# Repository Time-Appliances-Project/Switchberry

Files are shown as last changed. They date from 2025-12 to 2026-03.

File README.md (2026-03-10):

# Switchberry

## Raspberry Pi Compute Module based, Managed 1G Ethernet Switch with PTP Support
Switchberry is a Raspberry Pi CM4–controlled Ethernet switching + timing platform built around a **Microchip KSZ9567** and a **Renesas 8A34004 ClockMatrix DPLL**. It’s designed for **PTP / SyncE / timing lab** workflows while staying flexible enough to run as a compact managed switch/router with precise timing I/O.

529070621-42df475b-2fe9-462f-92c0-70f97fde4533

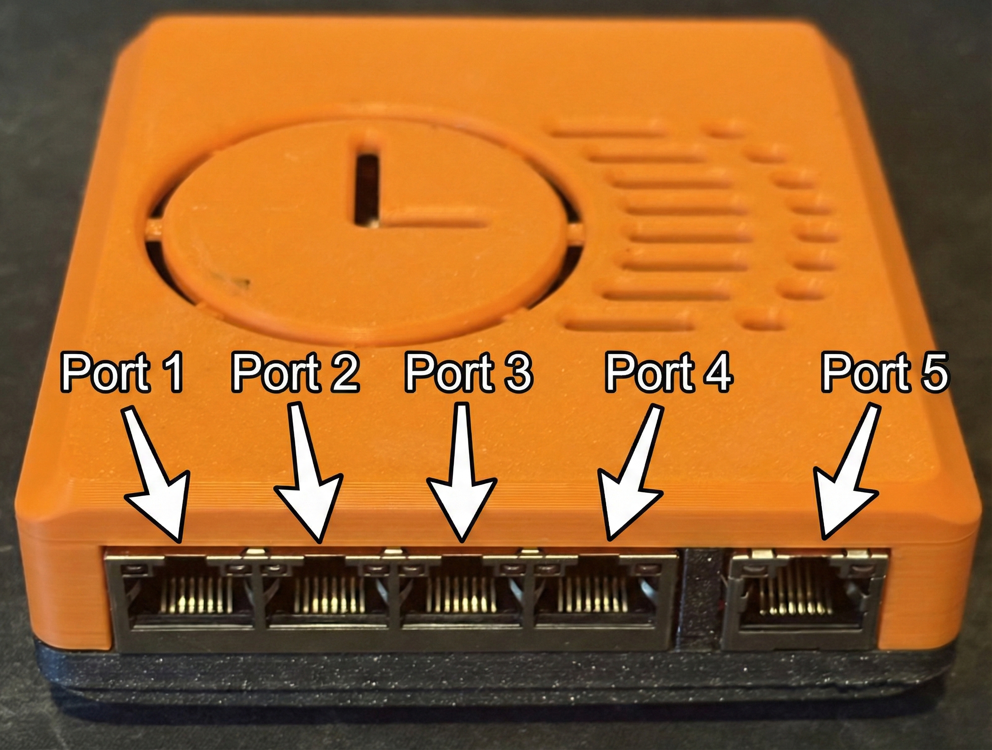
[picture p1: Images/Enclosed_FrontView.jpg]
Switchberry board Front view

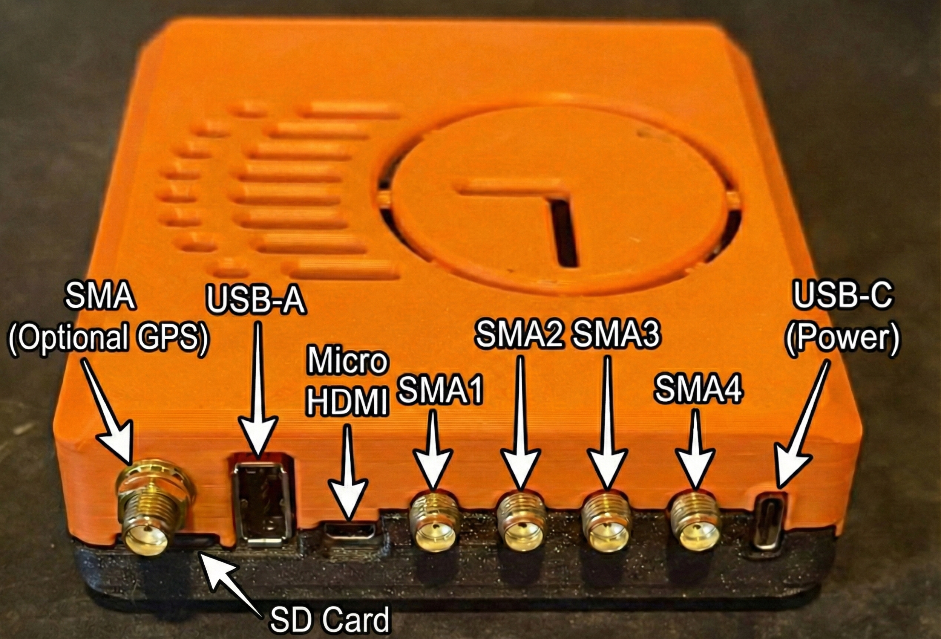
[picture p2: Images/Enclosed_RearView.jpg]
Switchberry board Rear view


---

## Order

**Switchberry is available for purchase on Tindie:**

👉 **[Buy Switchberry on Shopify](https://pmqipr-s3.myshopify.com/collections/switchberry-bundles)**

👉 **[Buy Switchberry on Tindie](https://www.tindie.com/products/timeappliances/switchberry/)**

---

## Table of Contents

- [Order](#order)

- [Quick Start](#quick-start)
  - [Out-of-the-Box Behavior](#out-of-the-box-behavior)
  - [Accessing the Raspberry Pi CM4](#accessing-the-raspberry-pi-cm4)
  - [Customize & Monitor](#customize--monitor)
- [Key Features](#key-features)
- [Hardware Overview](#hardware-overview)
- [Timing & Sync Capabilities](#timing--sync-capabilities)
- [Typical Use Cases](#typical-use-cases)
- [Notes](#notes)
- [License](#license)

**Software & Tools**

| Guide | Description |
| :--- | :--- |
| [Software Quick Start](Software/README.md) | Timing/PTP setup, config wizard, detailed from-scratch install |
| [Switch CLI](Software/switch/README.md) | KSZ9567 port status, counters, and init via SPI |
| [Daemons & Services](Software/daemons/README.md) | Systemd service chain, boot sequence, Makefile control |
| [ClockMatrix Utilities](Software/clockmatrix/README.md) | dplltool, config.py wizard, apply_timing.py, DPLL monitor |
| [Enclosure](Enclosure/README.md) | Enclosure design files |
| [Partial Schematic](PartialSchematic/README.md) | Board schematic reference |

---

## Quick Start

### Out-of-the-Box Behavior

With no configuration, Switchberry works as a **plug-and-play Layer 2 unmanaged Ethernet switch** with **PTP hardware transparent clock** enabled:

- **All 5 front-panel RJ45 ports** are on the same switch plane and forward traffic at line rate — just plug in Ethernet cables
- The CM4 is connected to the switch via an **internal port that is always up**, so **any front-panel port** can be used to reach the CM4 over the network
- **PTP transparent clock** is active by default — PTP packets are forwarded with hardware residence-time correction, no setup needed
- No VLANs, IP configuration, or switch management required to start using it as a switch

### Accessing the Raspberry Pi CM4

**Default login:** `pi` / `password`

The CM4 is available through three interfaces:

| Method | Connector | Details |
| :--- | :--- | :--- |
| **Ethernet (DHCP)** | Any front-panel RJ45 port | CM4 obtains an IP via DHCP. SSH in with `ssh pi@<ip-address>` — use `find_switchberry.py` or check your router to find the IP. |
| **Serial console** | Micro-USB (side panel) | Appears as a USB UART. Connect with **PuTTY** or **Tera Term** (Windows) or **tio** (Linux) at **115200 baud**. On a fresh SD card image, add `enable_uart=1` to `config.txt` first. |
| **Display + keyboard** | Micro-HDMI + USB-A | Connect a monitor via micro-HDMI and a keyboard via USB-A for direct console/desktop access. |

> **Tip:** Use `find_switchberry.py` from your PC to automatically discover Switchberry devices on your LAN:
> ```bash
> python3 find_switchberry.py
> ```

### Customize & Monitor

Clone the repo and make scripts executable:

```bash
cd ~/
git clone https://github.com/Time-Appliances-Project/Switchberry
cd Switchberry/Software
git config core.fileMode false
chmod +x sb-*.sh install_all.sh
```

Then configure and apply:

```bash
./sb-config.sh          # Interactive wizard — configure PTP role, timing sources, SMA routing
sudo ./sb-reinstall.sh  # Reinstall & restart (runs in background — safe over SSH)
./sb-status.sh          # Check DPLL lock state, PTP sync, and service health from the CLI
```

A **web status dashboard** also runs on port **8080** — open `http://<switchberry-ip>:8080` in any browser on the same network to see live system status.

For the full guide, see the **[Software Quick Start Guide](Software/README.md)**.

---

## Key Features

- **5× front-panel RJ45** ports driven by a **KSZ9567** switch
- **Raspberry Pi CM4** controller managing the switch over **SPI**
- **Renesas 8A34004 ClockMatrix DPLL** as the central timing hub
- **Local TCXO** reference for the ClockMatrix (drives derived clocks)
- **OCP M.2 GNSS** slot (GPS/GNSS timing card support)
- **PCIe M.2 2230** slot (Wi-Fi 6E / Wi-Fi 7 modules)
- **4× rear SMA** ports with muxing for multiple input/output routing options
- **SyncE recovery** from the switch into the DPLL (endpoint / boundary clock roles)
- **PTP modes**: hardware transparent clock (typical) or Linux DSA for software-defined behavior
- CM4 ↔ DPLL **PPS routing** supports both **PTP Grandmaster** and **PTP client** workflows

---

## Hardware Overview

### Ethernet Switching (KSZ9567)
- **Switch:** Microchip **KSZ9567**
- **Front panel:** **5× RJ45** ports
- **SFP:** Present on KSZ9567 but **unused** in this design (not used because it doesn’t support PTP)

### Controller / Host (CM4)
- **Compute:** Raspberry Pi **CM4**
- **Switch management:** CM4 controls the KSZ9567 over **SPI**
- **Uplink path to the switch:**
  - CM4 Ethernet MAC → **KSZ9031 PHY** → KSZ9567 (connected as one switch port)

### Timing Core (ClockMatrix)
- **DPLL:** **Renesas 8A34004 ClockMatrix**
  - Central point for all timing signals (distribution, recovery, synthesis)
- **Reference oscillator:** **Local TCXO**
  - Feeds the ClockMatrix and serves as the base reference for derived clocks

### Expansion
- **GNSS:** **OCP M.2 GNSS** slot for GPS/GNSS cards
- **Wi-Fi:** **PCIe M.2 2230** slot for Wi-Fi modules (Wi-Fi 6E / Wi-Fi 7 capable cards)

### Rear I/O (SMA)
- **4× SMA ports** on the back panel
- Each SMA has **muxing**, allowing configurable **input/output** options depending on timing mode and setup

---

## Timing & Sync Capabilities

### SyncE
- Switchberry can **recover the SyncE clock** from the **KSZ9567** and feed it into the **ClockMatrix DPLL**.
- Enables operation as a **SyncE endpoint** or **SyncE boundary clock** (and equivalent roles depending on configuration).

### PTP (IEEE 1588)
The KSZ9567 can be operated in multiple modes depending on the use case:

- **Transparent Clock (typical):**
  - KSZ9567 runs in **transparent clock mode** with **hardware forwarding**.
- **Linux DSA (optional):**
  - Run the switch under the **DSA kernel architecture** to behave more like a **software router**
  - Useful for experimentation with **boundary clock / software-defined forwarding** behavior

### PPS Routing (CM4 ↔ DPLL)
- The **PPS associated with the CM4 Ethernet port** routes to the **DPLL** as **both input and output**.
- Supports:
  - **PTP Grandmaster operation**
    - CM4 disciplines to a **PPS input from the DPLL**, derived from **GNSS** or an **external 1PPS** source.
  - **PTP client operation**
    - CM4 recovers timing via **PTP over the Ethernet switch** and provides **1PPS to the DPLL**.

---

## Typical Use Cases

- **PTP networking**
  - Transparent clock, boundary clock experimentation, lab deployments
- **SyncE networking**
  - Endpoint / boundary clock setups using recovered SyncE into the DPLL
- **PTP Grandmaster**
  - GNSS-referenced or externally referenced timing with PPS discipline
- **PTP client**
  - Recover PPS via PTP and feed the DPLL
- **TSN experimentation**
  - With additional scripting/development
- **DPLL development**
  - Clocking experiments, holdover testing, input qualification, output synthesis
- **Arbitrary frequency generator**
  - Using ClockMatrix outputs via configurable SMA routing
- **PPS ↔ frequency conversion**
  - Convert/derive timing signals via the DPLL and output routing
- **Wi-Fi bridge**
  - Wi-Fi 6E / Wi-Fi 7 connectivity via M.2 2230 (e.g., bridging/edge deployments)

---

## Notes

- The KSZ9567 **SFP port is unused** in this design because it doesn’t support PTP for the intended timing workflows.
- SMA functions are **mode-dependent** and determined by the mux configuration and ClockMatrix setup.

---

## License

This project is licensed under the Creative Commons Attribution-NonCommercial 4.0 International License (CC BY-NC 4.0).

You are free to:

Share — copy and redistribute the material in any medium or format
Adapt — remix, transform, and build upon the material
Under the following terms:

Attribution — You must give appropriate credit, provide a link to the license, and indicate if changes were made.
NonCommercial — You may not use the material for commercial purposes.
For full details, see: https://creativecommons.org/licenses/by-nc/4.0/

As the project creator, I reserve the right to use this material commercially or under any other terms.

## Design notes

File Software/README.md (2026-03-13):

# Switchberry Timing Quick Start

This guide gets you from “fresh install” to a working timing/PTP setup, and shows how to customize behavior using the `config.py` wizard and the daemon Makefile.

**↑ [Back to main README](../README.md)**

## Table of Contents

- [System Overview](#system-overview)
- [Default behavior (out of the box)](#default-behavior-out-of-the-box)
- [Quick start: customize your timing/PTP setup](#quick-start-customize-your-timingptp-setup)
- [Detailed setup](#detailed-setup)

**Related Guides:** [Switch CLI](switch/README.md) · [Daemons & Services](daemons/README.md) · [ClockMatrix Utilities](clockmatrix/README.md)

### System Overview

```mermaid
graph TD
    subgraph Sources [Timing Sources]
        GPS[GPS Receiver]
        SyncE[SyncE Network]
        SMA_In[SMA Inputs]
    end

    subgraph Switchberry
        direction TB
        DPLL[8A34004 DPLL]
        CM4[Compute Module 4]
        Switch[KSZ9567 Switch]
    end

    subgraph Outputs [Timing Distribution]
        PTP[PTP Network]
        SMA_Out[SMA Outputs]
    end

    %% Flow
    GPS -->|1PPS| DPLL
    SMA_In -->|Freq/Time| DPLL
    SyncE -->|Recovered Clock| Switch
    Switch -->|25MHz Ref| DPLL

    DPLL -->|1PPS| CM4
    DPLL -->|Freq & 1PPS| SMA_Out
    
    CM4 -->|System Time| PTP
    Switch -->|PTP Packets| PTP
```

---

## Default behavior (out of the box)

If you haven’t customized `/etc/startup-dpll.json`, the default setup is:

### PTP
- **Role:** **Grandmaster (GM)**
- **Mode:** **Unicast** (reduces message flooding; safer on shared networks)

### Input priorities
- **Time sources**
  1. **GPS** (highest priority for time)
  2. **SMA4** = 1PPS input (fallback time behind GPS)

- **Frequency sources**
  1. **SMA1** = 10MHz input (highest priority for frequency)

### Outputs
- **SMA3** = 1PPS output (or other frequency)
- **SMA2** = 10MHz output (**frequency-only**, V6 board - not phase-aligned)

> **V6 Board Note:** **SMA2** is routed via Channel 5 (SyncE frequency channel) and only
> provides frequency alignment, not phase alignment. For phase-aligned 1PPS output,
> use **SMA4** instead (which is routed via Channel 6).

### Advanced: Hardware SMA Mapping
For users debugging schematics or low-level GPIO code, here is the mapping between Rear-Panel labels (User) and Schematic labels (Hardware):

| User Label (Rear) | Hardware Label (Schematic) |
| :--- | :--- |
| **SMA1** | SMA4 |
| **SMA2** | SMA3 |
| **SMA3** | SMA2 |
| **SMA4** | SMA1 |

### NTP Server (GM+GPS only)

When configured as a **PTP Grandmaster with GPS**, Switchberry automatically serves **NTP** (Stratum 1) to the local network. The full time chain is:

```
GPS → DPLL → ts2phc → PHC (TAI) → phc2sys (-O -37) → System Clock (UTC) → chrony → NTP
```

- **Guard script** (`switchberry_chrony_guard.sh`): Only starts `chronyd` once `ts2phc` has converged. If GPS is lost or the DPLL goes unstable, chrony is stopped so stale time is never served. It restarts automatically when GPS recovers.
- **Config:** `/etc/switchberry/chrony-switchberry.conf`
- NTP is **not served** in CLIENT or NONE modes.

> **Dependency:** `chrony` must be installed: `sudo apt install chrony`.
> The stock `chronyd.service` is automatically disabled by `sb-reinstall.sh` to prevent port 123 conflicts.

#### Testing NTP from another device

From any device on the same network as the Switchberry:

**Linux:**
```bash
ntpdate -q <switchberry-ip>
# Install if missing: sudo apt install ntpdate
```

**macOS:**
```bash
sntp <switchberry-ip>
```

**Windows (PowerShell):**
```powershell
w32tm /stripchart /computer:<switchberry-ip> /samples:3
```

You should see **Stratum 1** and an offset near zero (a few ms is normal over Ethernet).

### System Clock Sync (GM+GPS and CLIENT)

The system clock (`CLOCK_REALTIME`) is automatically synced from the PHC via `phc2sys` in both **GM+GPS** and **CLIENT** modes:

- **GM+GPS:** `phc2sys` starts when `ts2phc` converges (PHC has GPS time).
- **CLIENT:** `phc2sys` starts when `ptp4l` is locked (servo `s2`, tight offsets).
- **Guard script** (`switchberry_phc2sys_guard.sh`): Stops `phc2sys` when the upstream time source is lost, restarts when recovered.
- **TAI→UTC:** `phc2sys` runs with `-O -37` to convert from the PHC's TAI time to the system clock's UTC.

---

## Quick start: customize your timing/PTP setup

### 1) Clone the github software
```bash
cd ~/
git clone https://github.com/Time-Appliances-Project/Switchberry
cd Switchberry/Software 
git config core.fileMode false
chmod +x sb-*.sh install_all.sh
```

### 2) Run the config wizard
This script runs the wizard and automatically installs the generated configuration to `/etc/startup-dpll.json`.

```bash
./sb-config.sh
```

### 3) Apply changes and restart services
This script recompiles tools, installs services, and restarts the PTP stack.

```bash
sudo ./sb-reinstall.sh
```

### 4) Check Status
Monitor DPLL lock state, PTP synchronization, and service health.

```bash
./sb-status.sh
```

### 5) Web Status Dashboard
A built-in web server runs on port **8080** (HTTP) and **8443** (HTTPS), showing a live dashboard with system identity, configuration, service status, DPLL state, and PTP sync info. It auto-refreshes every 10 seconds.

From any browser on the same network, open:
```
http://<switchberry-ip>:8080
```

> **Tip:** Use the `find_switchberry.py` script (in the repo root) from your PC to automatically discover Switchberry devices on your LAN:
> ```bash
> python3 find_switchberry.py
> ```

### 6) (Optional) Customize PTP configuration
If you need to change PTP profiles (e.g. Unicast vs Multicast), edit the config files managed by the services:
- Client: `~/Switchberry/Software/daemons/ptp4l-switchberry-client.conf`
- Grandmaster: `~/Switchberry/Software/daemons/ptp4l-switchberry-gm.conf`
Then run `sudo ./sb-reinstall.sh` to apply.

## Detailed setup 

This section is only if you want to start from a fresh SD card for instance. 

To access the Switchberry, you can use 

1. Micro-HDMI for monitor, USB-A for keyboard
2. Micro-USB on side. This will come up as UART to the CM4.
	To access this with a fresh SD card, you'll need to edit config.txt into the SD card to enable the UART.

In config.txt, add these at the end under [all]:

```bash
dtparam=spi=on
enable_uart=1
uart_2ndstage=1
dtoverlay=disable-bt
dtoverlay=switchberrytc
#dtoverlay=ksz9567
dtoverlay=spi0-1cs
dtoverlay=uart5,txd5_pin=12,rxd5_pin=13
dtoverlay=pcie-32bit-dma
dtparam=i2c_vc=off
hdmi_force_hotplug=1
```

### 1) Setup SD-card
Edit config.txt in bootfs of SD card like above. Enables UART and boot without monitor.

### 2) Clone the github software
```bash
cd ~/
git clone https://github.com/Time-Appliances-Project/Switchberry
cd Switchberry 
```

### 3) Install a bunch of dependencies

```bash
sudo apt update
sudo apt install bc bison flex libssl-dev make screen vim automake iperf tshark autoconf libmnl-dev libmnl-doc jq gpsd gpsd-clients socat linuxptp 
```

### 4) Clone kernel sources
Instructions for building CM4 kernel are here: https://www.raspberrypi.com/documentation/computers/linux_kernel.html

```bash 
cd ~/
mkdir kernel
cd kernel
git clone --depth=1 https://github.com/raspberrypi/linux
cd linux
# updated .config with additional items needed by switchberry like MDIO and others 
cp ~/Switchberry/Software/kernel/.config ./.config
# device tree overlays for switchberry, for both default ("Transparent clock") and DSA ("Boundary clock"), and Makefile
cp ~/Switchberry/Software/kernel/ksz9567-overlay.dts arch/arm/boot/dts/overlays/
cp ~/Switchberry/Software/kernel/switchberrytc-overlay.dts arch/arm/boot/dts/overlays/
cp ~/Switchberry/Software/kernel/copy_Makefile arch/arm/boot/dts/overlays/Makefile
```

### 5) Rebuild kernel with updated config and overlays

This step will take significant time!
```bash 
cd ~/kernel/linux
KERNEL=kernel8

# THIS STEP ESPECIALLY takes a long time , I run it in screen so if you disconnect it keeps going
#screen -S test # do this if you're familiar with screen so ssh connection can drop 
# if it asks questions, just hold enter for defaults
make -j6 Image.gz modules dtbs ; sudo make -j6 modules_install

KERNEL=kernel8
sudo cp /boot/firmware/$KERNEL.img /boot/firmware/$KERNEL-backup.img
sudo cp arch/arm64/boot/Image.gz /boot/firmware/$KERNEL.img
sudo cp arch/arm64/boot/dts/broadcom/*.dtb /boot/firmware/
sudo cp arch/arm64/boot/dts/overlays/*.dtb* /boot/firmware/overlays/
sudo cp arch/arm64/boot/dts/overlays/README /boot/firmware/overlays/
```

### 6) Reboot

```bash
sudo reboot
```

### 7) Install third party dependencies

#### spidev-test

```bash
cd ~/kernel/linux/tools/spi
make clean; make all; sudo make install
```

#### mdio-tools

```bash
cd ~/
git clone https://github.com/wkz/mdio-tools
cd mdio-tools/kernel
KDIR=~/kernel/linux/
make all; sudo make install 
cd .. 
./autogen.sh
./configure --prefix=/usr && make all && sudo make install
```

#### testptp

```bash
cd ~/kernel/linux/tools/testing/selftests/ptp
gcc -Wall -lrt testptp.c -o testptp
sudo cp testptp /usr/bin/
```

### 8) Build & Install everything for Switchberry

```bash
cd ~/Switchberry/Software/
chmod +x install_all.sh
sudo ./install_all.sh
```

### 9) Customize 

Follow quick-start guide above at this point, everything should be installed!

You need to create a /etc/startup-dpll.json for everything to get configured and operate properly.

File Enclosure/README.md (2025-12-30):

# Switchberry 3D Printed Case Instructions



The Switchberry 3D case is designed to be printed in two parts: a top cover and bottom plate. The bottom has two holes for heatsinks / airflow, and the top is ventilated in case you'd like to add on a fan, attached to the small JST SH (1mm) fan header on the Switchberry.

The 3D printable STL files are available in this directory:

  - [Switchberry_Case_v5_Top.stl](Switchberry_Case_v5_Top.stl)
  - [Switchberry_Case_v5_Bottom.stl](Switchberry_Case_v5_Top.stl)

It is recommended you print the top out of a material which can take some heat without deforming. The Switchberry shouldn't get *too* hot, but using PETG or ASA is a better option than PLA.

## Needed parts

The links below go to Amazon, but you can buy these parts from wherever you'd like:

  - [4x M3x10 (+6mm) Male to Female Brass Threaded Spacers](https://www.amazon.com/dp/B07BLSRZYJ) (to provide adequate space between the top cover and the PCB)
  - [4x M3x12 SHCS Screws](https://www.amazon.com/dp/B0FGV5FCBN) (to attach the bottom to the top)
  - [4x round rubber feet](https://www.amazon.com/dp/B08GLJB3Z4) (to hold Switchberry stably on a desk or shelf, and provide convective airflow under the board)



  1. Print the top and bottom case on a 3D printer (no supports required). I printed mine in ASA/PLA, but any material should be okay, depending on your environmental conditions and printer capabilities.
  3. Screw the M3x10 threaded spacers into the standoffs in the top case; this will require some force, so it is recommended you use a nut driver instead of trying to thread them in by hand.
  3. (Optionally, if using M.2 GPS module) Install GPS module into Switchberry, and plug in GPS U.FL to SMA female cable. Insert female SMA end into the hole in the top case and secure with included nut.
  4. Place the Switchberry board into the top case, Ethernet port side first, and ensure everything is aligned properly.
  5. Place the bottom cover over the Switchberry board, being careful to start with the post between the Ethernet ports (it will need to seat into the recess in the top cover), then make the rest of the case flush with the top cover.
  6. Screw four M3x12 SHCS screws into the four screw holes in the bottom cover. These can be a tight fit, depending on the accuracy of your 3D print.
  7. Place four adhesive rubber feet over the four circular foot pads on the bottom cover.

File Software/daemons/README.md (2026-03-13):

# Switchberry Daemons & Makefile Control

This directory contains the **systemd services** that bring up Switchberry’s timing + switch + PTP stack, plus a **Makefile** that installs and controls the whole set.

---

## Boot / runtime service chain

The system is intended to start in this order:

```mermaid
sequenceDiagram
    participant Boot as System Boot
    participant Apply as apply-timing.service
    participant Init as full-init.service
    participant Monitor as dpll-monitor.service
    participant Role as ptp-role.service
    participant PTP as PTP Daemons

    Note over Boot,PTP: Systemd Dependency Chain

    Boot->>Apply: 1. Program 8A34004 (DPLL)
    Apply->>Init: 2. Initialize Switch (KSZ9567)
    Init->>Monitor: 3. Start DPLL Monitor
    Init->>Role: 4. Determine PTP Role
    Role->>PTP: 5. Launch ptp4l / ts2phc
```

1. **Init DPLL + board multiplexers**
   - **Service:** `switchberry-apply-timing.service`
   - **Runs:** `/usr/local/sbin/apply_timing.py -c /etc/startup-dpll.json`
   - **What it does:** Programs the 8A34004 ClockMatrix runtime config and configures board muxes so PPS/clock signals are routed as intended.

2. **Init switch defaults (Transparent Clock enabled, SyncE output disabled by default)**
   - **Service:** `switchberry-full-init.service`
   - **Runs:** `/usr/local/sbin/full_init.sh`
   - **What it does:** Initializes the KSZ9567 into a known-good default state (typically TC mode with hardware forwarding). SyncE output is not enabled here by default.

3. **DPLL monitor / relock workaround**
   - **Service:** `switchberry-dpll-monitor.service`
   - **Runs:** `/usr/local/sbin/fastlock_1pps_fix.sh`
   - **What it does:** Monitors DPLL lock state and intervenes to force relock in edge cases (e.g. channels unlocking). This may coincide with brief relocks/phase jumps on PPS outputs.

4. **GNSS access plumbing (optional / image-dependent; “needs to be done” on some images)**
   - **Services:** `gpsd.service`, `gpspipe-socat.service`
   - **What it does:** Exposes GNSS/NMEA to other programs via gpsd and a simple relay.
   - **Note:** `gpsd.service` is often OS-provided and may not exist on every image.

5. **PTP role orchestration**
   - **Service:** `switchberry-ptp-role.service`
   - **Runs:** `/usr/local/sbin/switchberry-ptp-role.sh`
   - **What it does:** Starts the correct PTP daemons based on your configured role.

6. **Role-specific services started by `switchberry-ptp-role.sh`**
   - **Grandmaster (GM):**
     - `ts2phc-switchberry.service` — disciplines the CM4 Ethernet PHC from the timing chain
     - `ptp4l-switchberry-gm.service` — runs ptp4l as a GM
     - `switchberry-phc2sys.service` — syncs system clock from PHC (gated on ts2phc convergence)
     - `switchberry-chrony.service` — serves NTP using PHC refclock (gated on ts2phc convergence, GM+GPS only)
   - **Client:**
     - `ptp4l-switchberry-client.service` — runs ptp4l as a client (often unicast; user supplies GM IP in config)
	 - `switchberry-cm4-pps-monitor.service` — ensures PPS output from CM4 only when ptp4l is running and locked
     - `switchberry-phc2sys.service` — syncs system clock from PHC (gated on ptp4l lock quality)

7. **System clock and NTP features**
    - **phc2sys guard** (`switchberry_phc2sys_guard.sh`): Supervises `phc2sys` to copy PHC → `CLOCK_REALTIME`.
      In GM mode, gates on ts2phc status. In CLIENT mode, gates on ptp4l being locked (s2 + tight offsets).
      Stops phc2sys when upstream is lost, restarts when recovered.
    - **chrony guard** (`switchberry_chrony_guard.sh`): Supervises `chronyd` with a PHC refclock config.
      Only runs in GM+GPS mode. Gates on ts2phc convergence (PHC has GPS-accurate time).
      Stops chrony when GPS/DPLL is lost so stale time is never served.

---

## Key config

- **Timing config (used at boot):** `/etc/startup-dpll.json`  
  Consumed by `switchberry-apply-timing.service` via `apply_timing.py`.

---

## Makefile usage

This repo ships a `Makefile` that installs systemd units + helper scripts + config files, and provides convenient `systemctl`/`journalctl` wrappers to start/stop/check the Switchberry stack.

### Quick commands

```bash
# Show available targets
make

# Install everything, reload systemd, and enable default boot services
sudo make install

# Start/stop the full stack (in dependency-aware order)
make start
make stop

# Restart the full stack 
make restart

# Status + logs
make status
make logs S=switchberry-ptp-role.service

# Uninstall everything
sudo make uninstall 

```

---

## Testing NTP

When Switchberry is running as a **GM with GPS**, it serves NTP on the standard port (UDP 123).
To verify from another device on the same network:

### Linux
```bash
# One-shot query (shows offset, delay, stratum)
ntpdate -q <switchberry-ip>

# If ntpdate is not installed:
sudo apt install ntpdate
```

### macOS
```bash
# Built-in sntp utility
sntp <switchberry-ip>
```

### Windows (PowerShell)
```powershell
# Built-in w32tm utility
w32tm /stripchart /computer:<switchberry-ip> /samples:3
```

### Expected output
- **Stratum 1** — direct GPS/PHC hardware reference
- **Offset** near zero (a few milliseconds is normal over Ethernet)

> **Note:** `chrony` must be installed on the Switchberry image (`sudo apt install chrony`).
> The stock `chronyd.service` is automatically disabled by `sb-reinstall.sh` to avoid port conflicts.

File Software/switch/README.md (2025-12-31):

# KSZ9567 Switch CLI

A small Bash CLI for interacting with a **Microchip KSZ9567** Ethernet switch (via Linux SPI / `spidev`) to do common operational tasks like **port status**, **counters**, and **initialization**.

Run everything through the entrypoint:

```bash
./switch_cli.sh <command> [subcommand] [args...]
```

## Features

1. Port status / control (e.g., show link state, enable/disable ports)

2. Counters (read and clear per-port statistics)

3. Initialization (apply a known-good init sequence for your board / wiring)

## Requirements

Linux with SPI enabled and a /dev/spidev* device node

spidev_test available in PATH (or adjust the scripts to point to it)

Typically needs sudo to access /dev/spidev*

```bash
Quick start
chmod +x switch_cli.sh
sudo ./switch_cli.sh --help
```

Usage
Port status
```bash
./switch_cli.sh port status
./switch_cli.sh port status <port> [<port> ...]
```

Enable / disable ports
```bash
sudo ./switch_cli.sh port enable <port> [<port> ...]
sudo ./switch_cli.sh port disable <port> [<port> ...]
```

Read / clear counters
```bash
sudo ./switch_cli.sh counters read [<port> ...]
sudo ./switch_cli.sh counters clear [<port> ...]
```

Initialize the switch
```bash
sudo ./switch_cli.sh switch init
```

Project layout

switch_cli.sh — CLI entrypoint / dispatcher

ksz9567_spi.sh — low-level SPI + register helpers

commands/ — subcommands (ports, counters, switch operations)

Tip: Run switch_cli.sh from the repo root so relative paths resolve correctly.

Safety notes

This tool performs direct register access. Misconfiguration can disrupt traffic.

Run init on a maintenance window the first time, and validate on your target board.

Contributing

PRs welcome—especially for:

Additional subcommands (VLANs, QoS, mirroring, etc.)

Better board/port mapping configuration

Packaging (install script, completion, manpage)

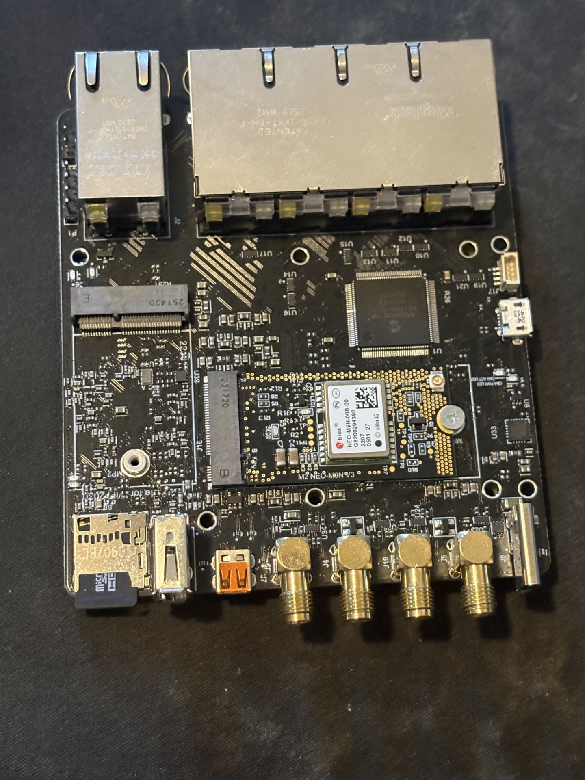
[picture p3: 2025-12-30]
Images/Board_TopView.jpg

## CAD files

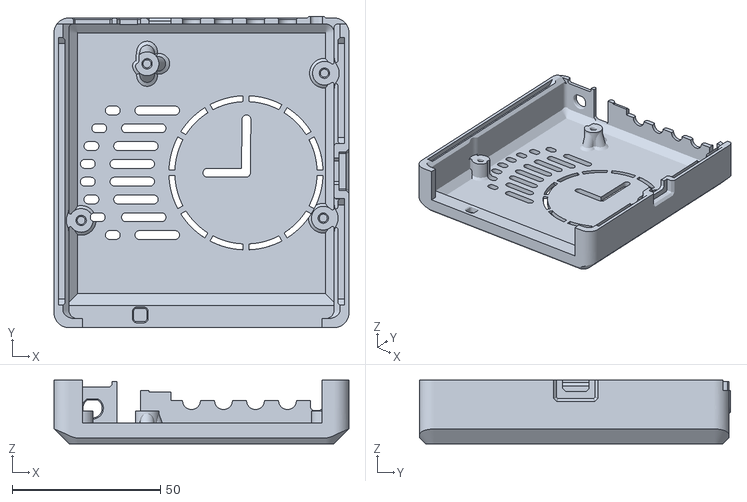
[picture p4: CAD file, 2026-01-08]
Enclosure/Switchberry_Case_v5_Top.stl
99.5 x 104.9 x 21.5

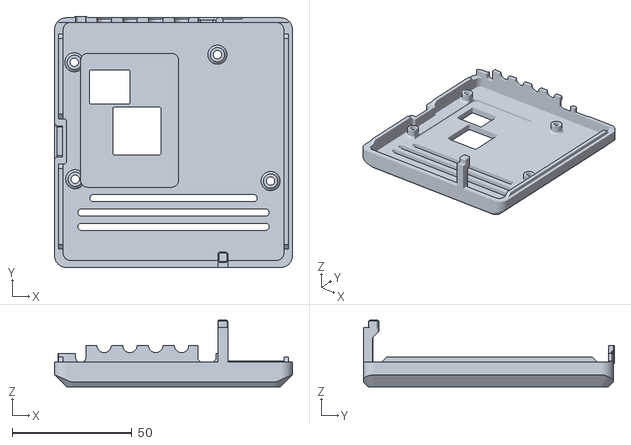
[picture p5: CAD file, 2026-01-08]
Enclosure/Switchberry_Case_v5_Bottom.stl
99.5 x 104.9 x 27.9

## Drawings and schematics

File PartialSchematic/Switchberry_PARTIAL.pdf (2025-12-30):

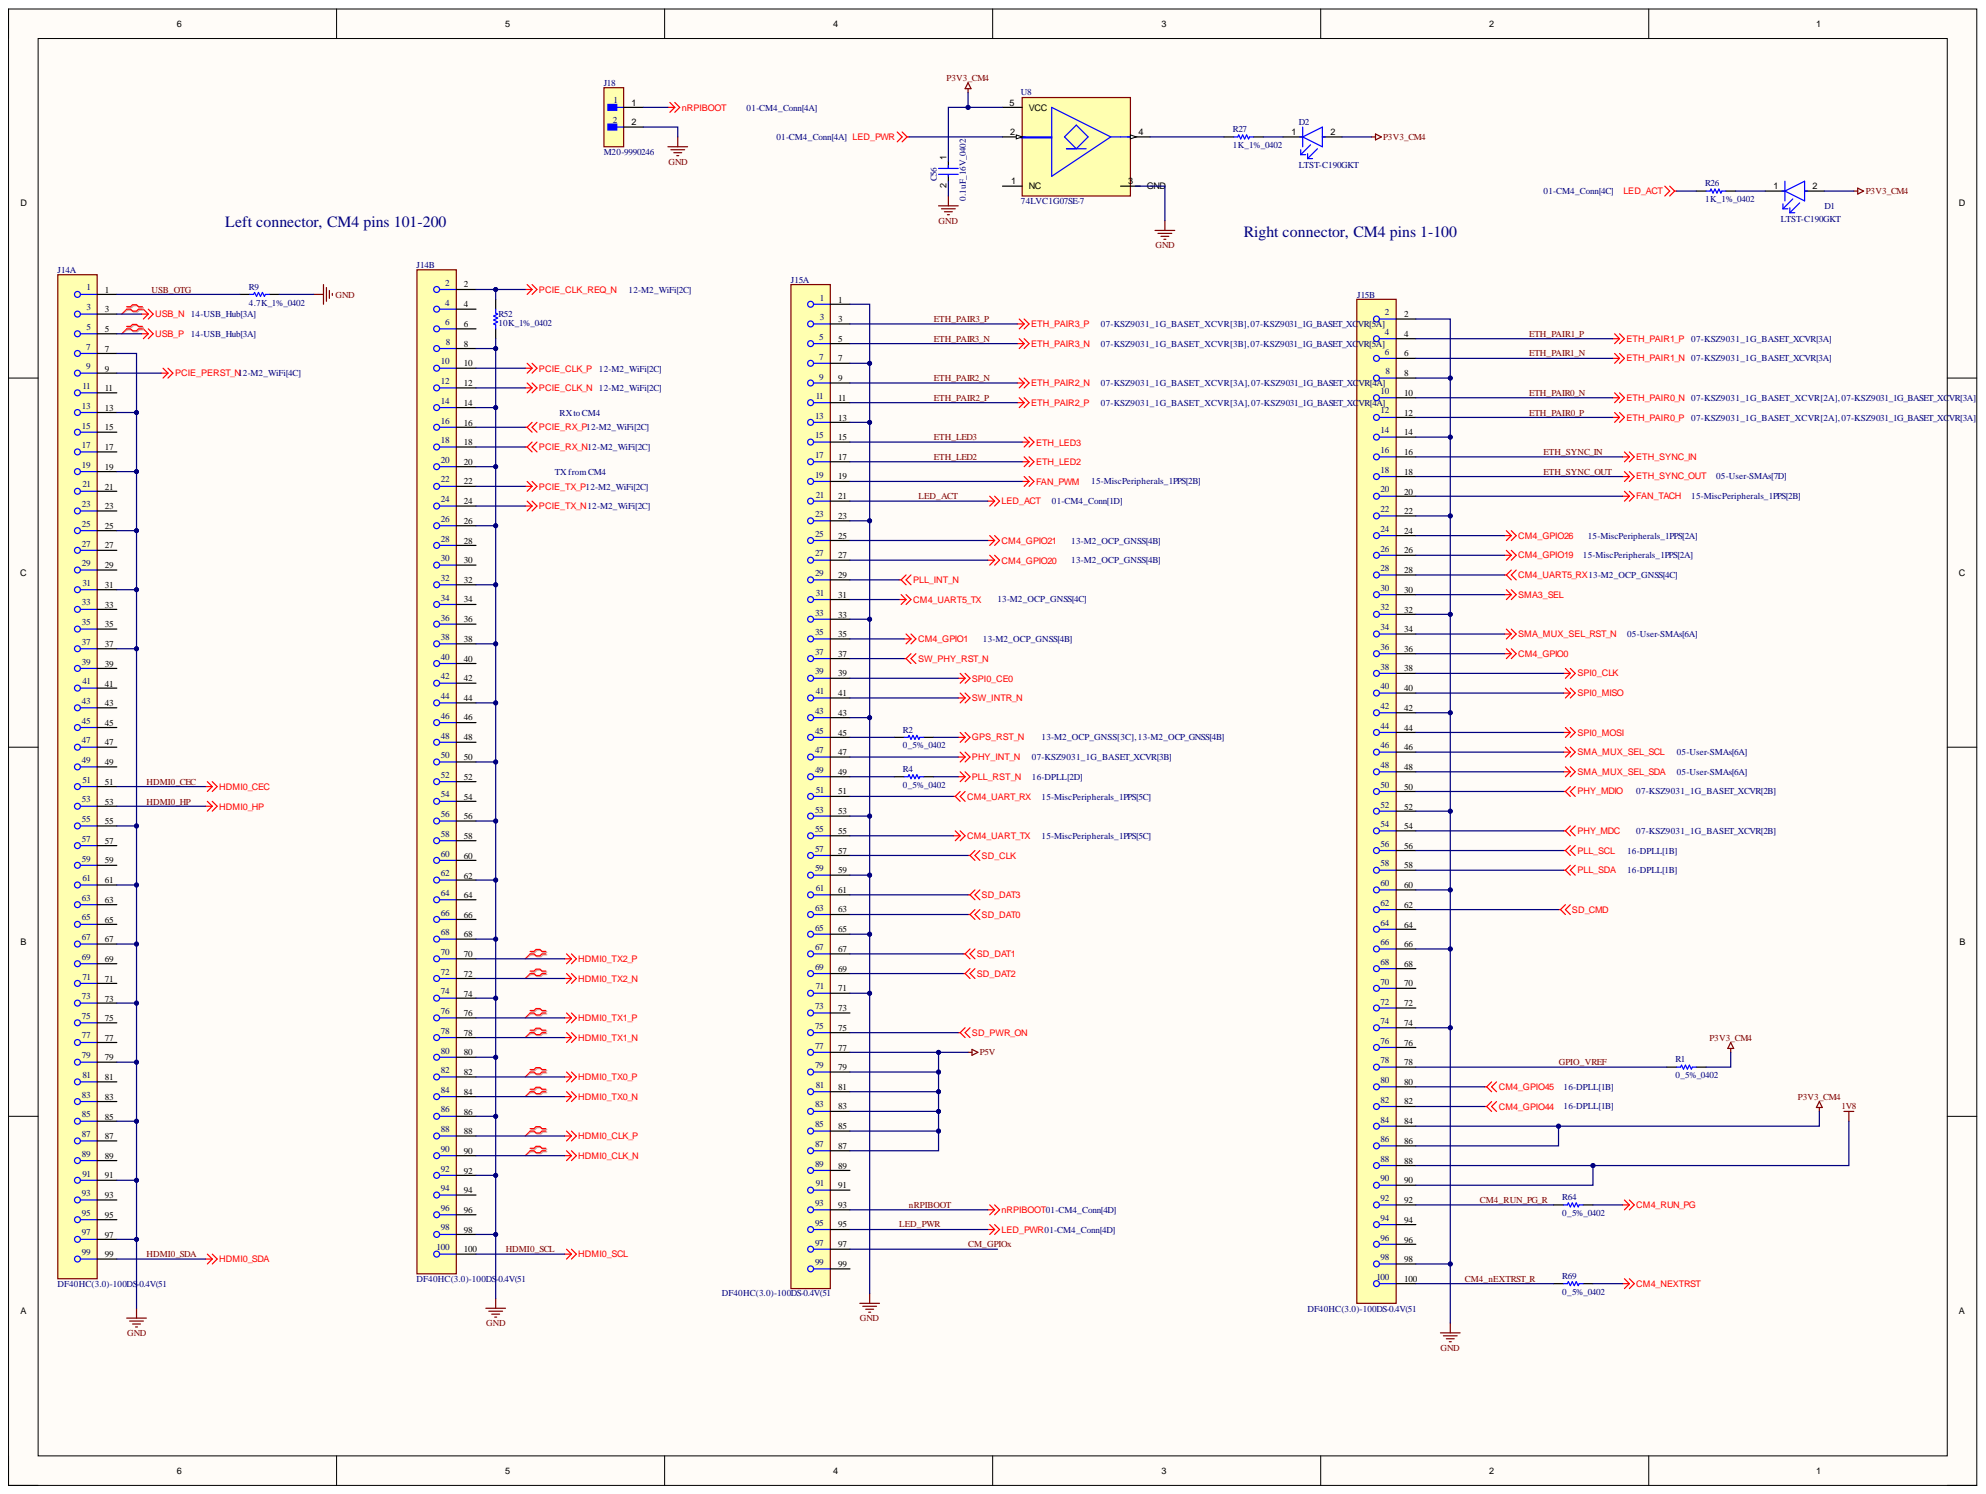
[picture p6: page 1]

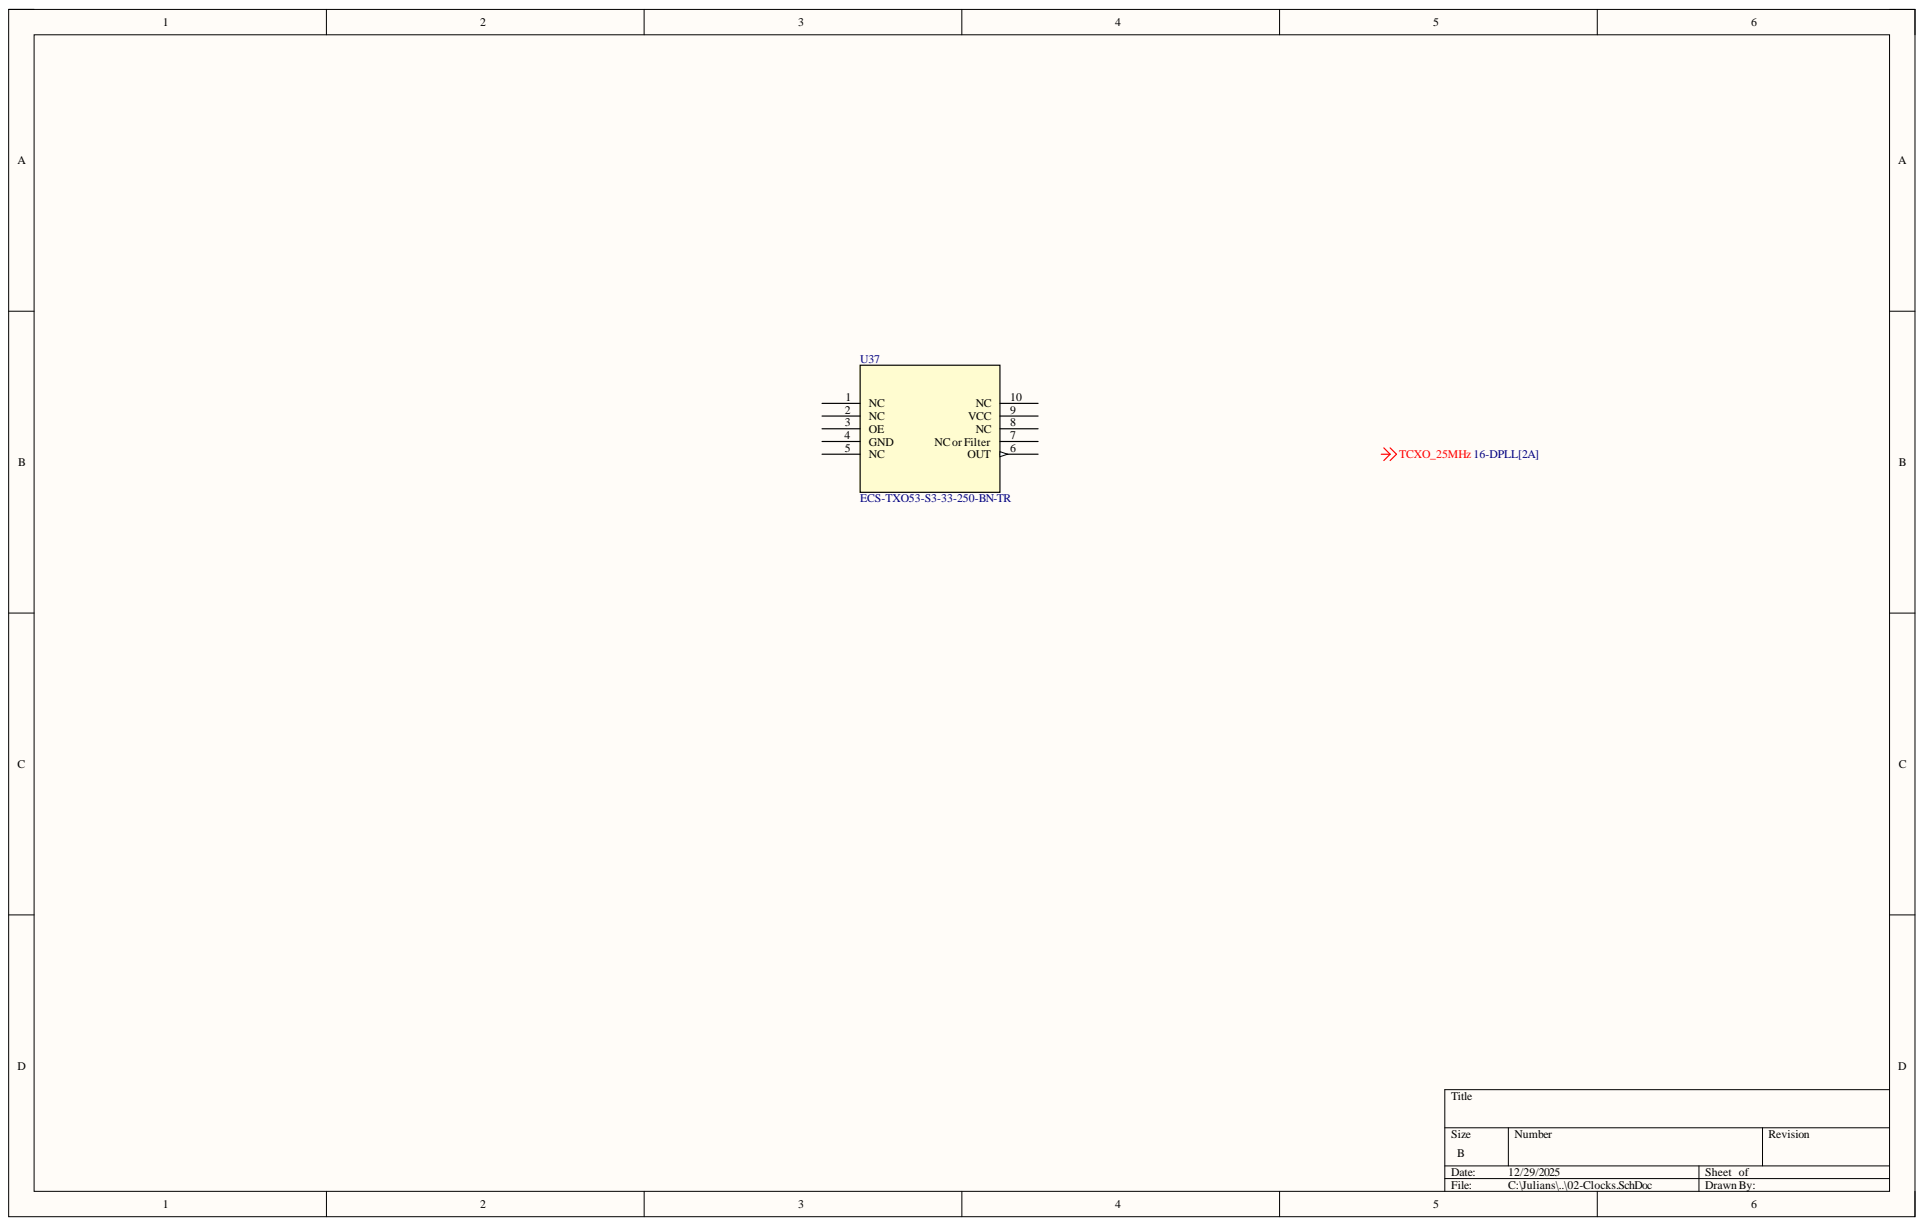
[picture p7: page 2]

Size B | Number | Revision

Date: 12/29/2025 | Sheet of
File: C:\Julians\..\02-Clocks.SchDoc | Drawn By:

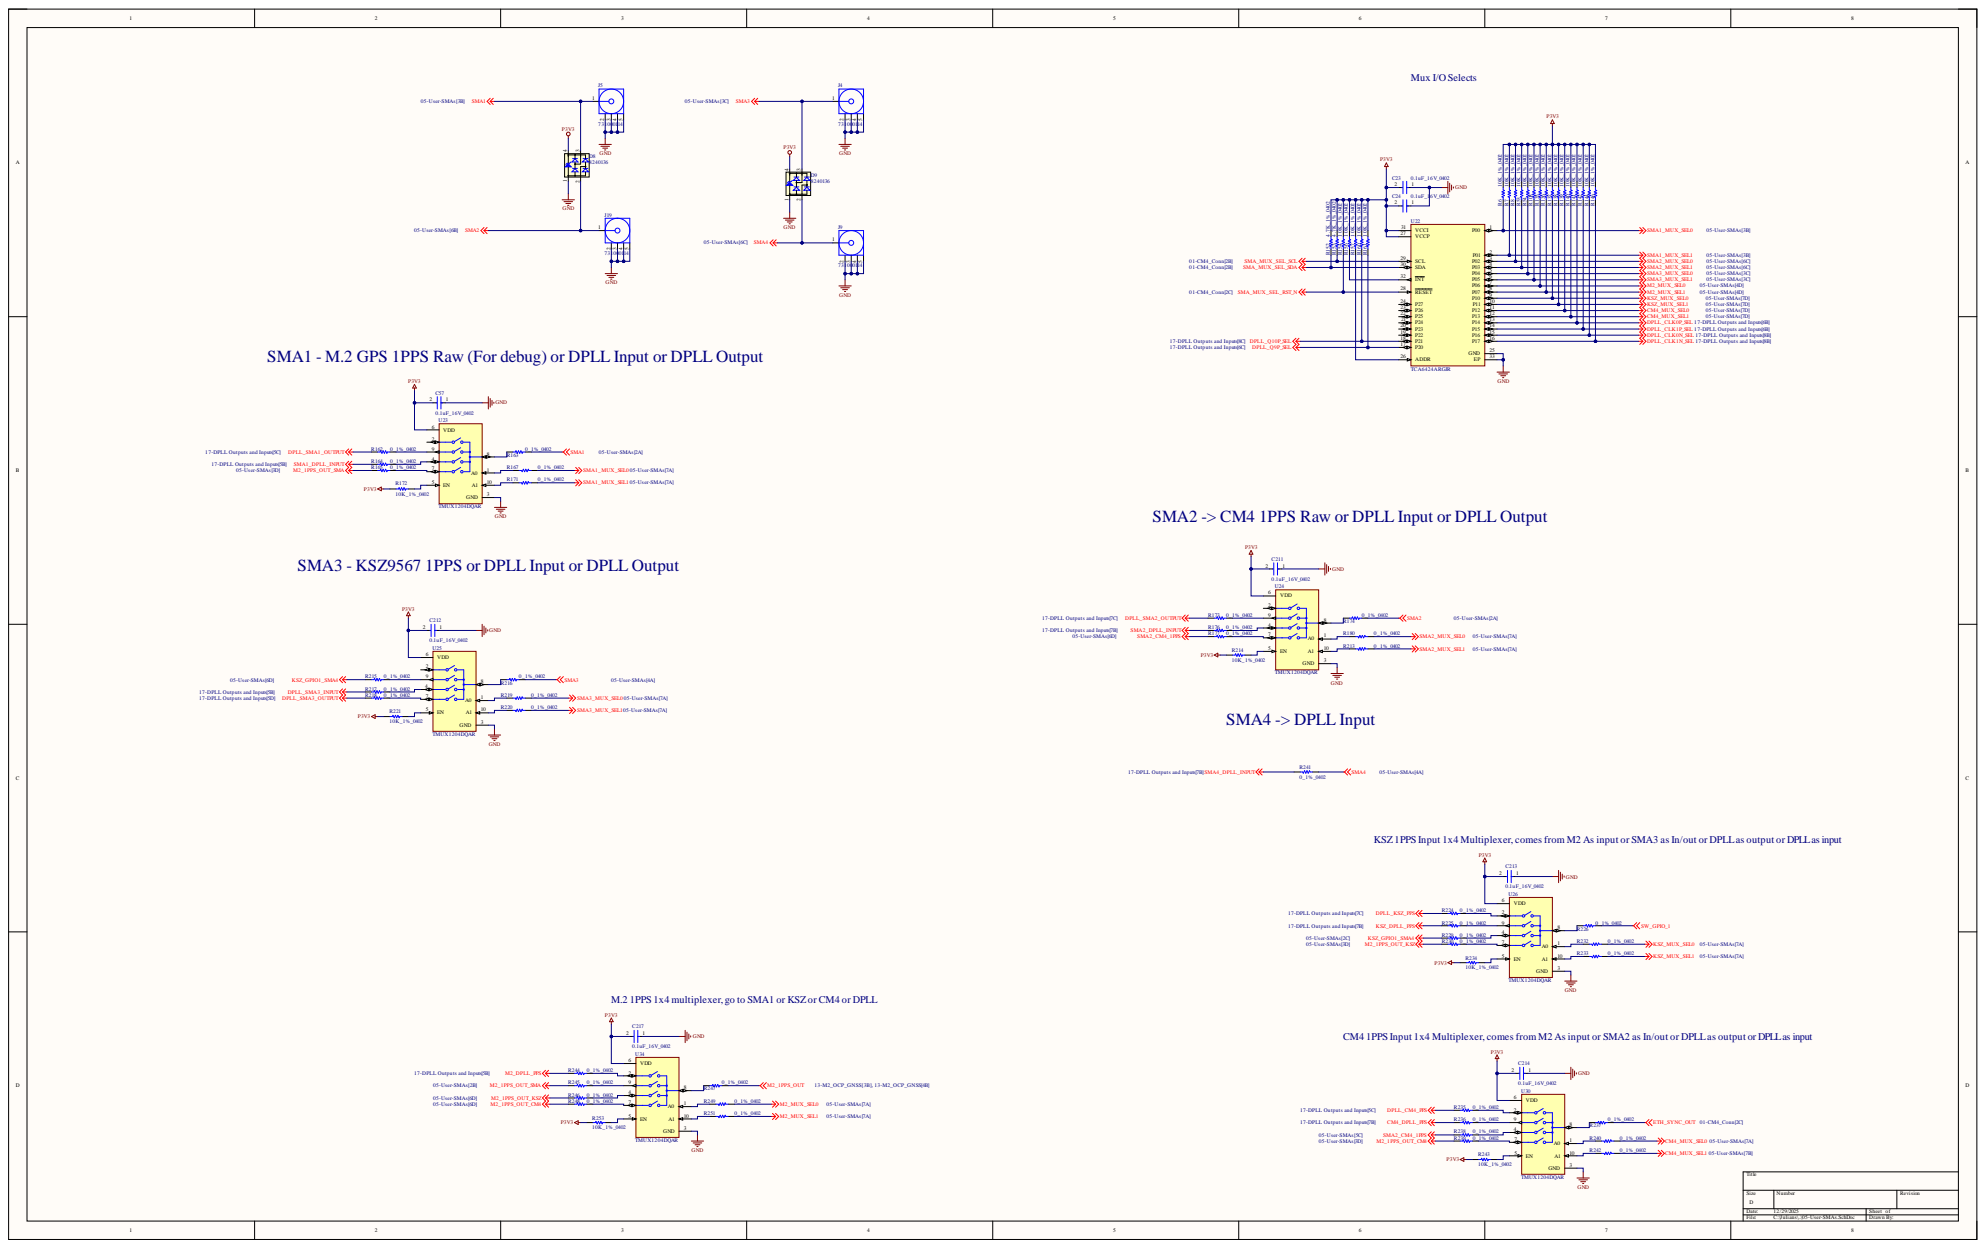
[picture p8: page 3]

SDA 30 INT 32

DPLL_CLK0P_SEL 17-DPLL Outputs and Inputs[6B]
DPLL_CLK1P_SEL 17-DPLL Outputs and Inputs[6B]
DPLL_CLK0N_SEL 17-DPLL Outputs and Inputs[8B]
DPLL_CLK1N_SEL 17-DPLL Outputs and Inputs[8B]

RESET 28

17-DPLL Outputs and Inputs[8C] DPLL_Q10P_SEL

SMA1 - M.2 GPS 1PPS Raw (For debug) or DPLL Input or DPLL Output

SMA2 -> CM4 1PPS Raw or DPLL Input or DPLL Output

SMA3 - KSZ9567 1PPS or DPLL Input or DPLL Output

17-DPLL Outputs and Inputs[7B]SMA4_DPLL_INPUT

KSZ 1PPS Input 1x4 Multiplexer, comes from M2 As input or SMA3 as In/out or DPLLas output or DPLLas input

M.2 1PPS 1x4 multiplexer, go to SMA1 or KSZ or CM4 or DPLL

CM4 1PPS Input 1x4 Multiplexer, comes from M2 As input or SMA2 as In/out or DPLLas output or DPLLas input

Size D | Number | Revision

Date: 12/29/2025 | Sheet of

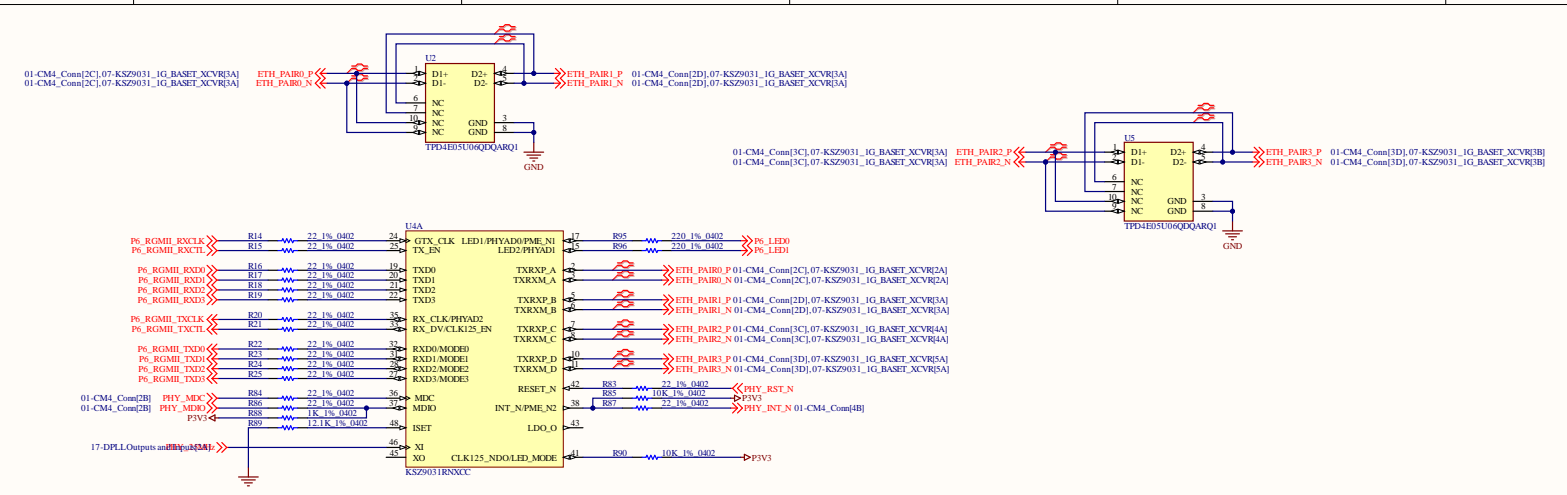
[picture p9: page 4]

7 | NC NC
1 0 | NC G ND | 3

7 | NC
1 0 | NC NC G ND NC G ND

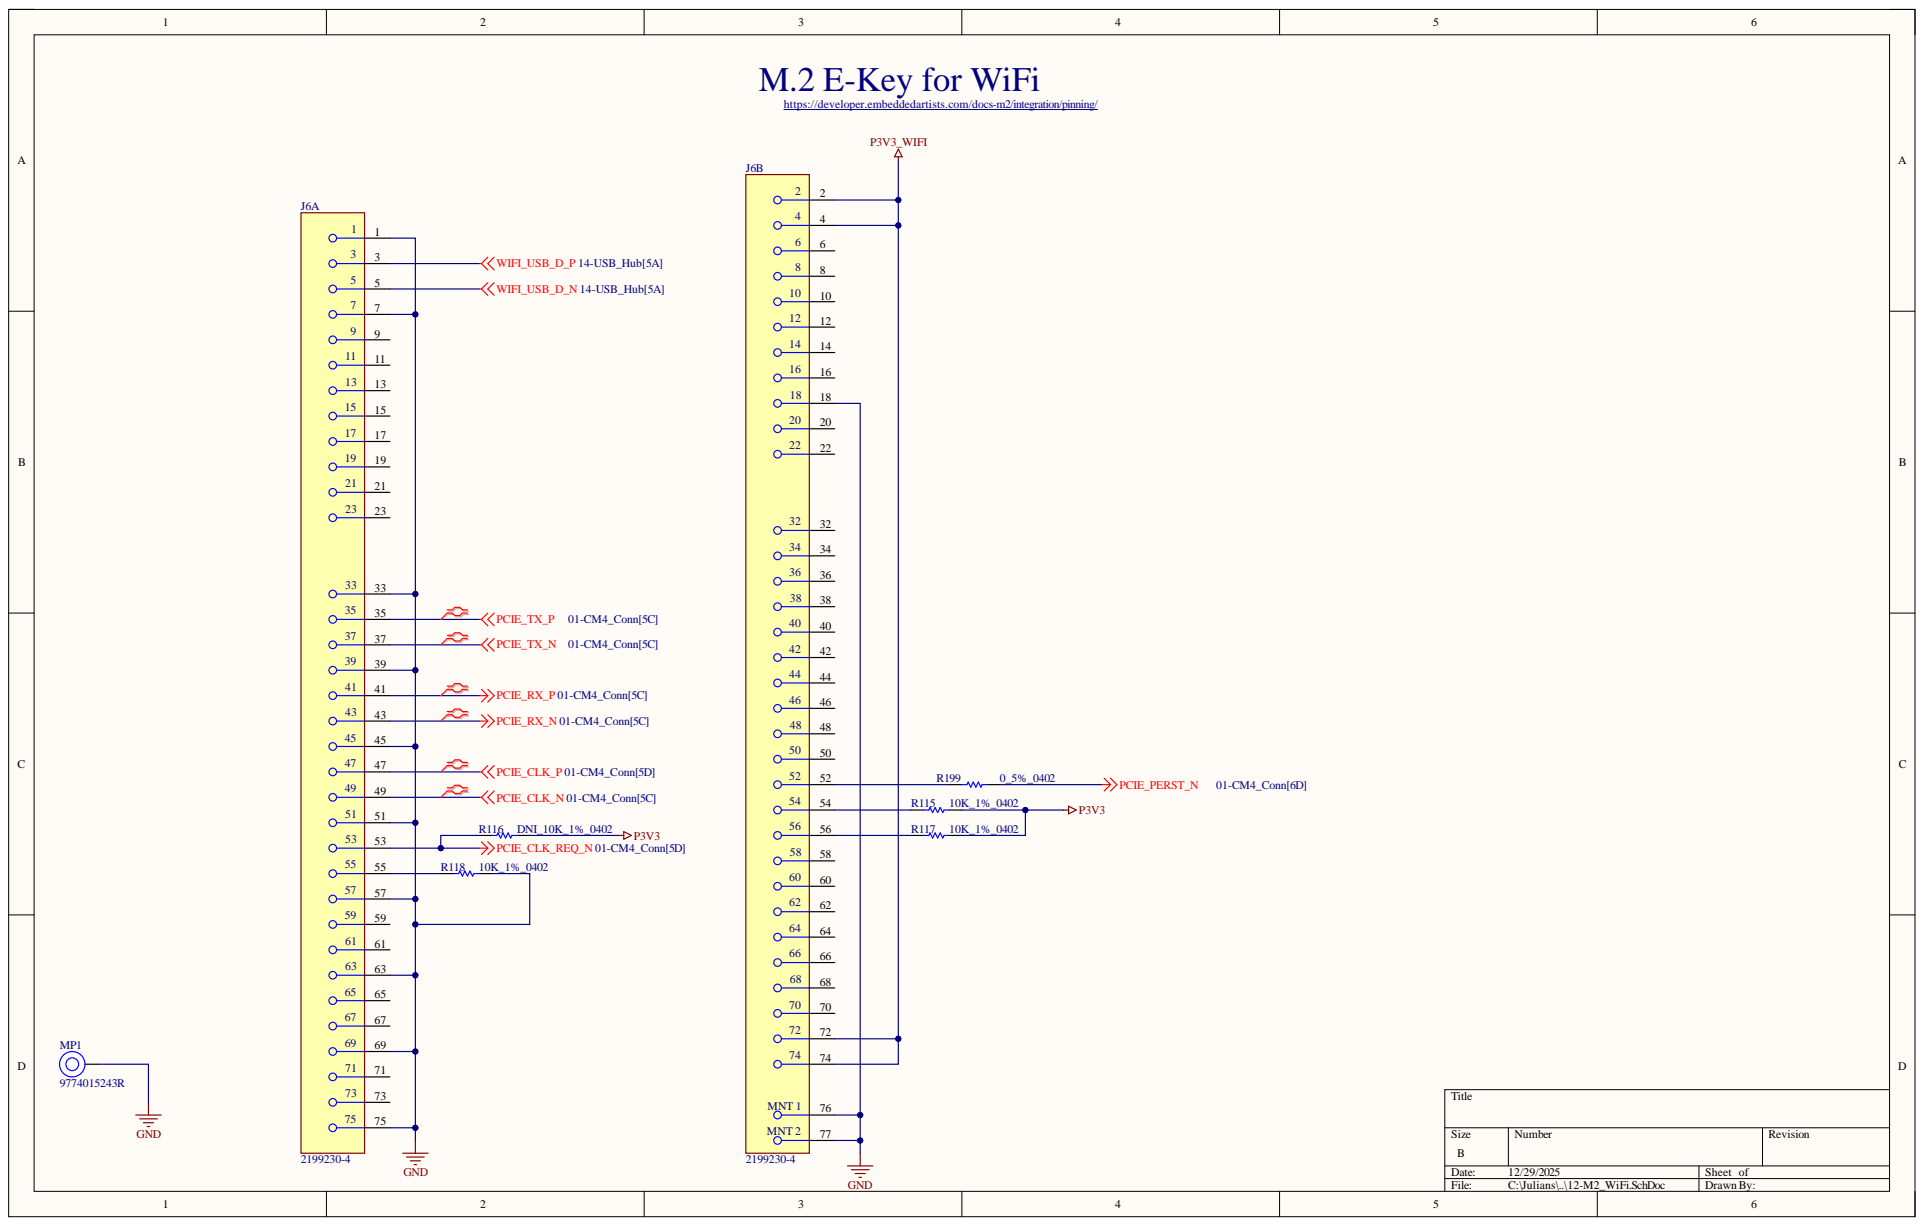
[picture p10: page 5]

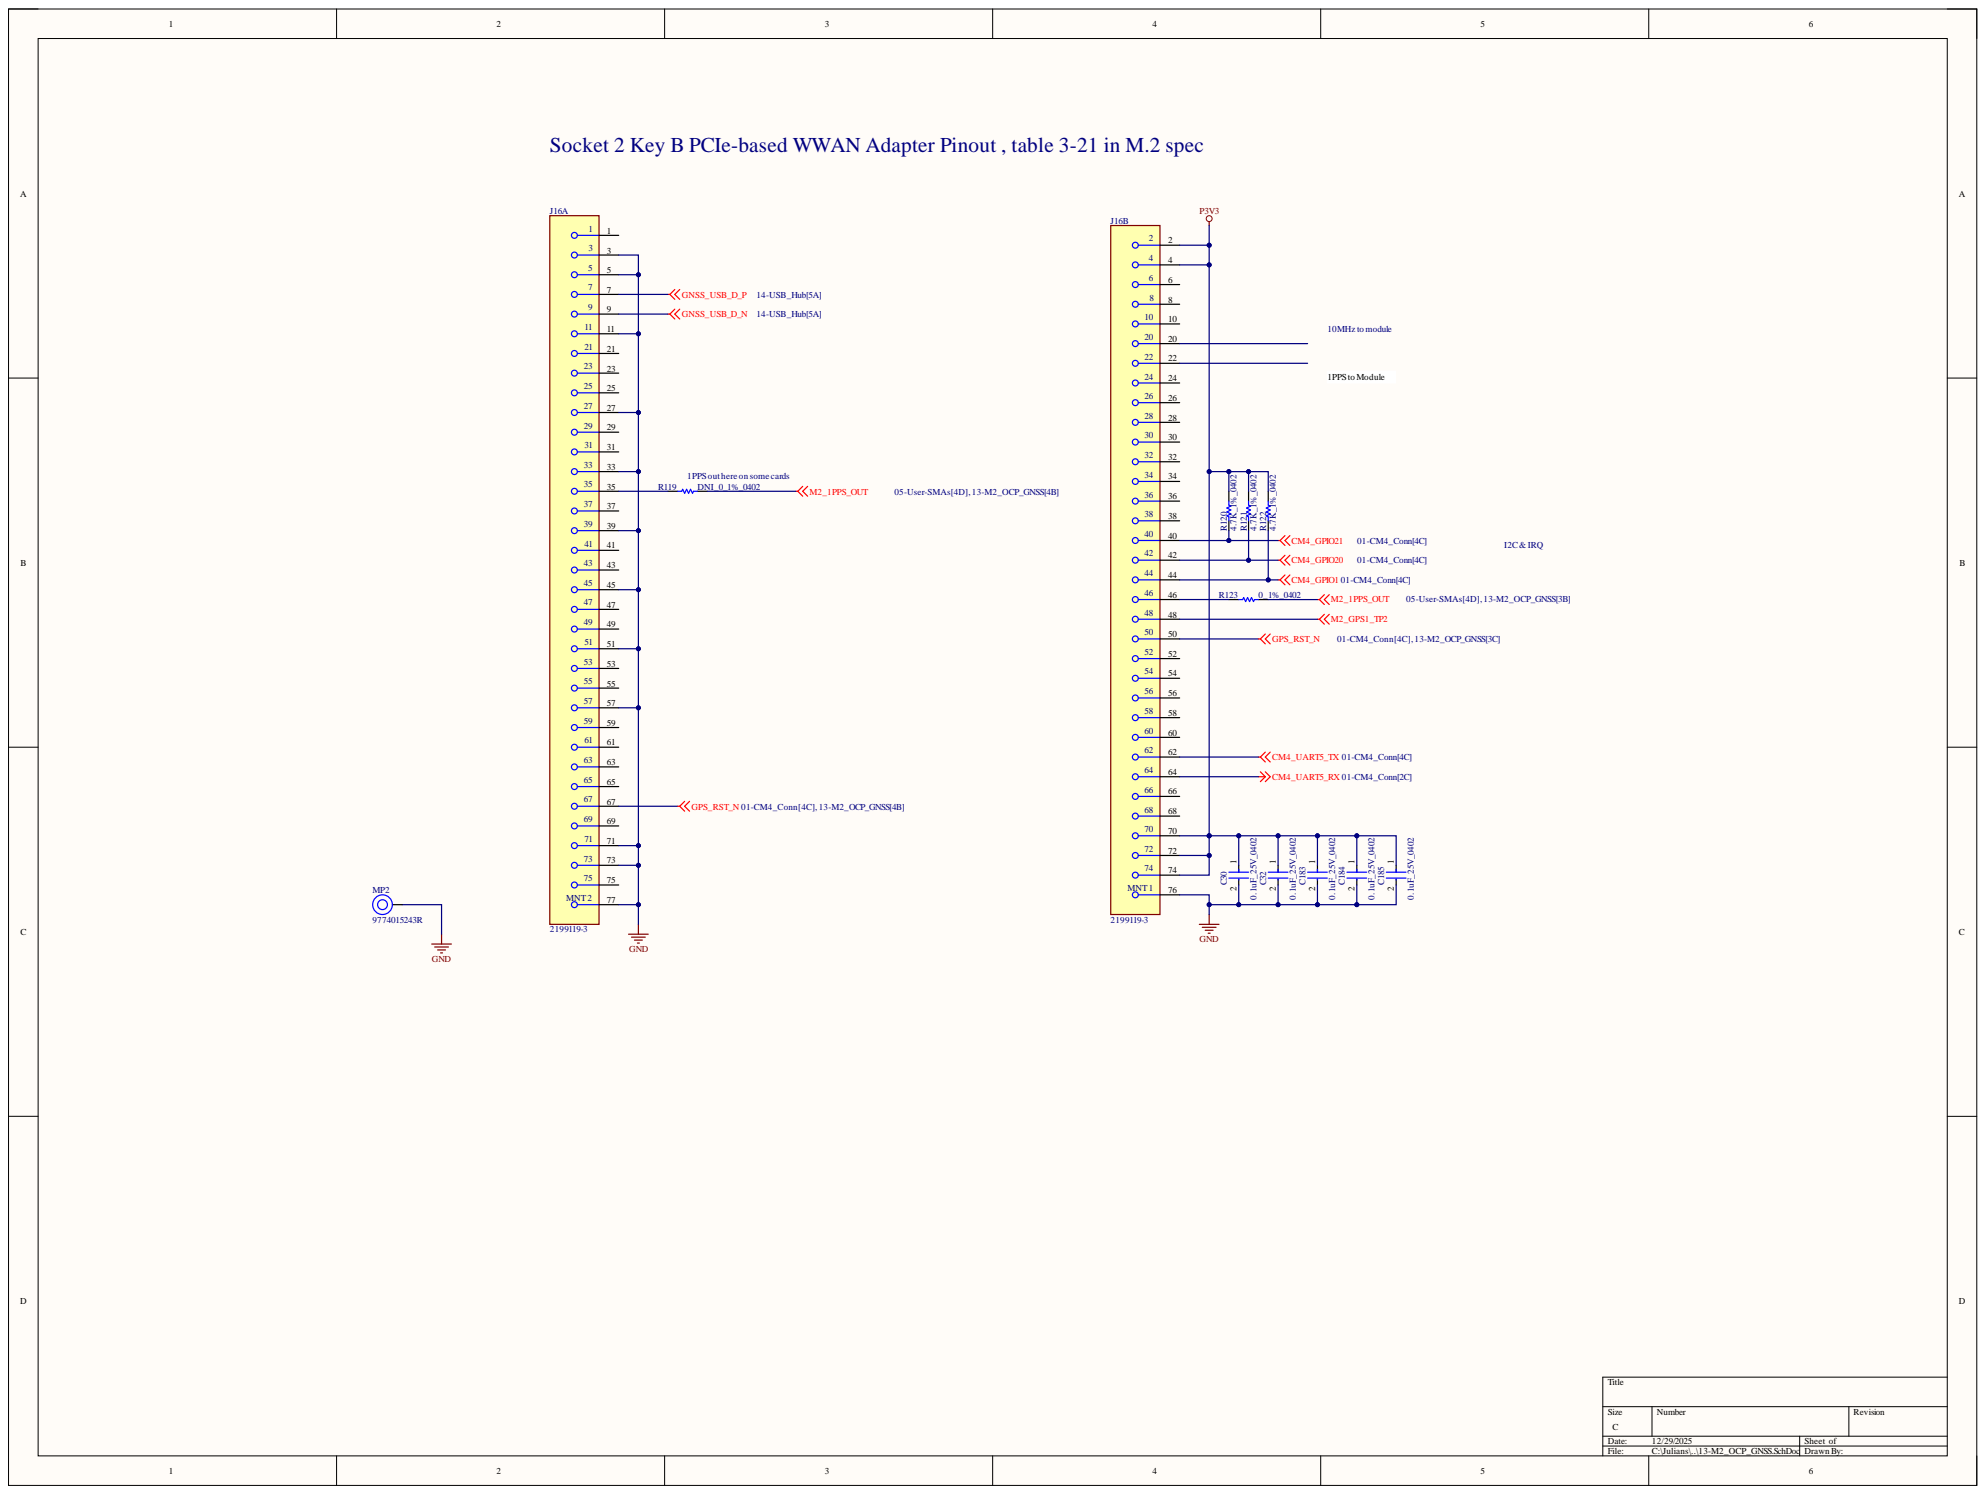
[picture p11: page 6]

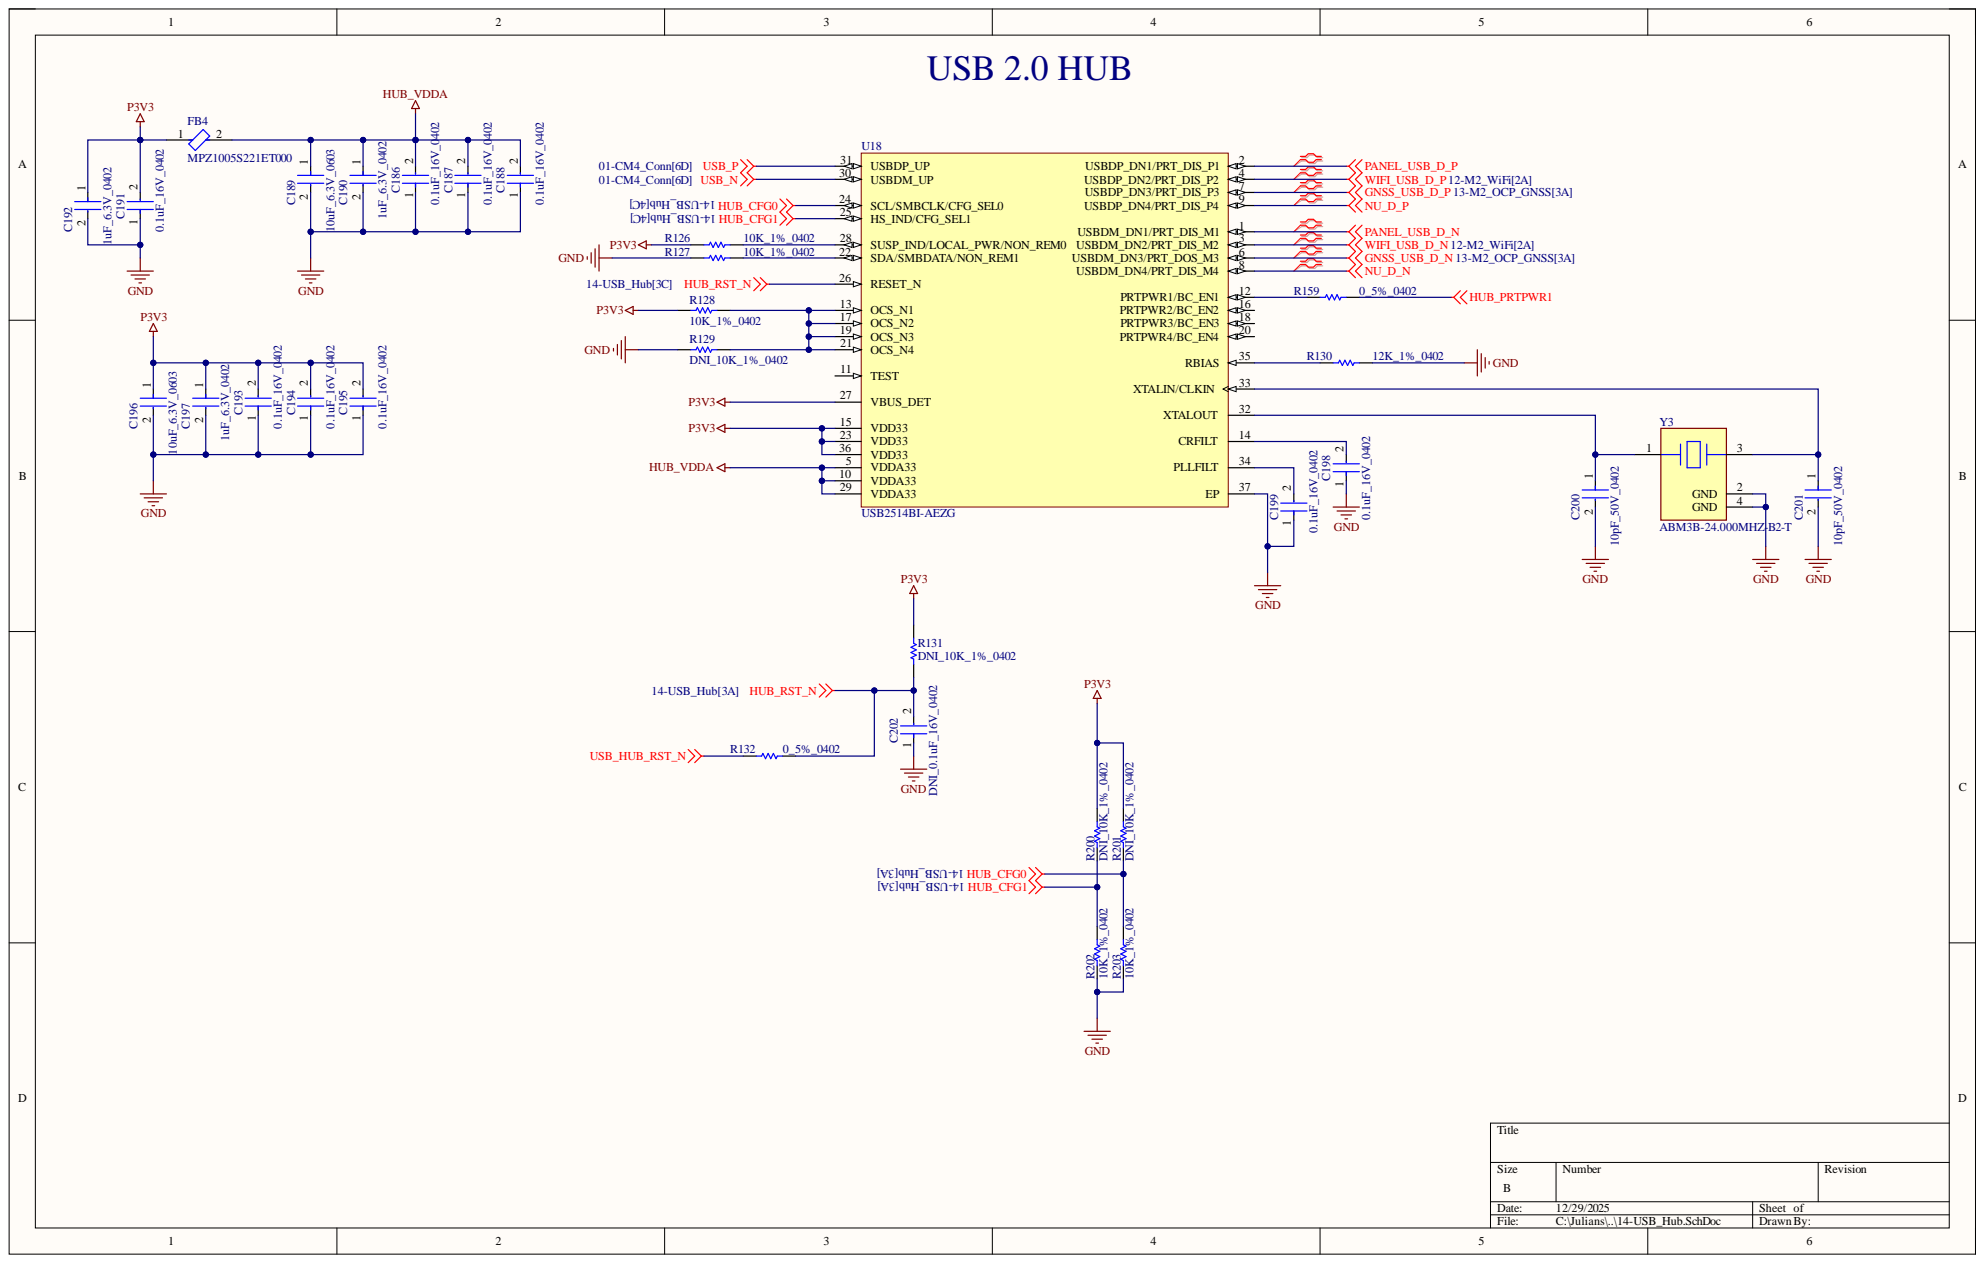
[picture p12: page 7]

Si z e | Num b er | Revi s i on

e : 12/29/ 20 2 5 | Sheet of
Fi l e : C : \Jul ians \..\14-USB_Hub.S chDo c | D rawn By:

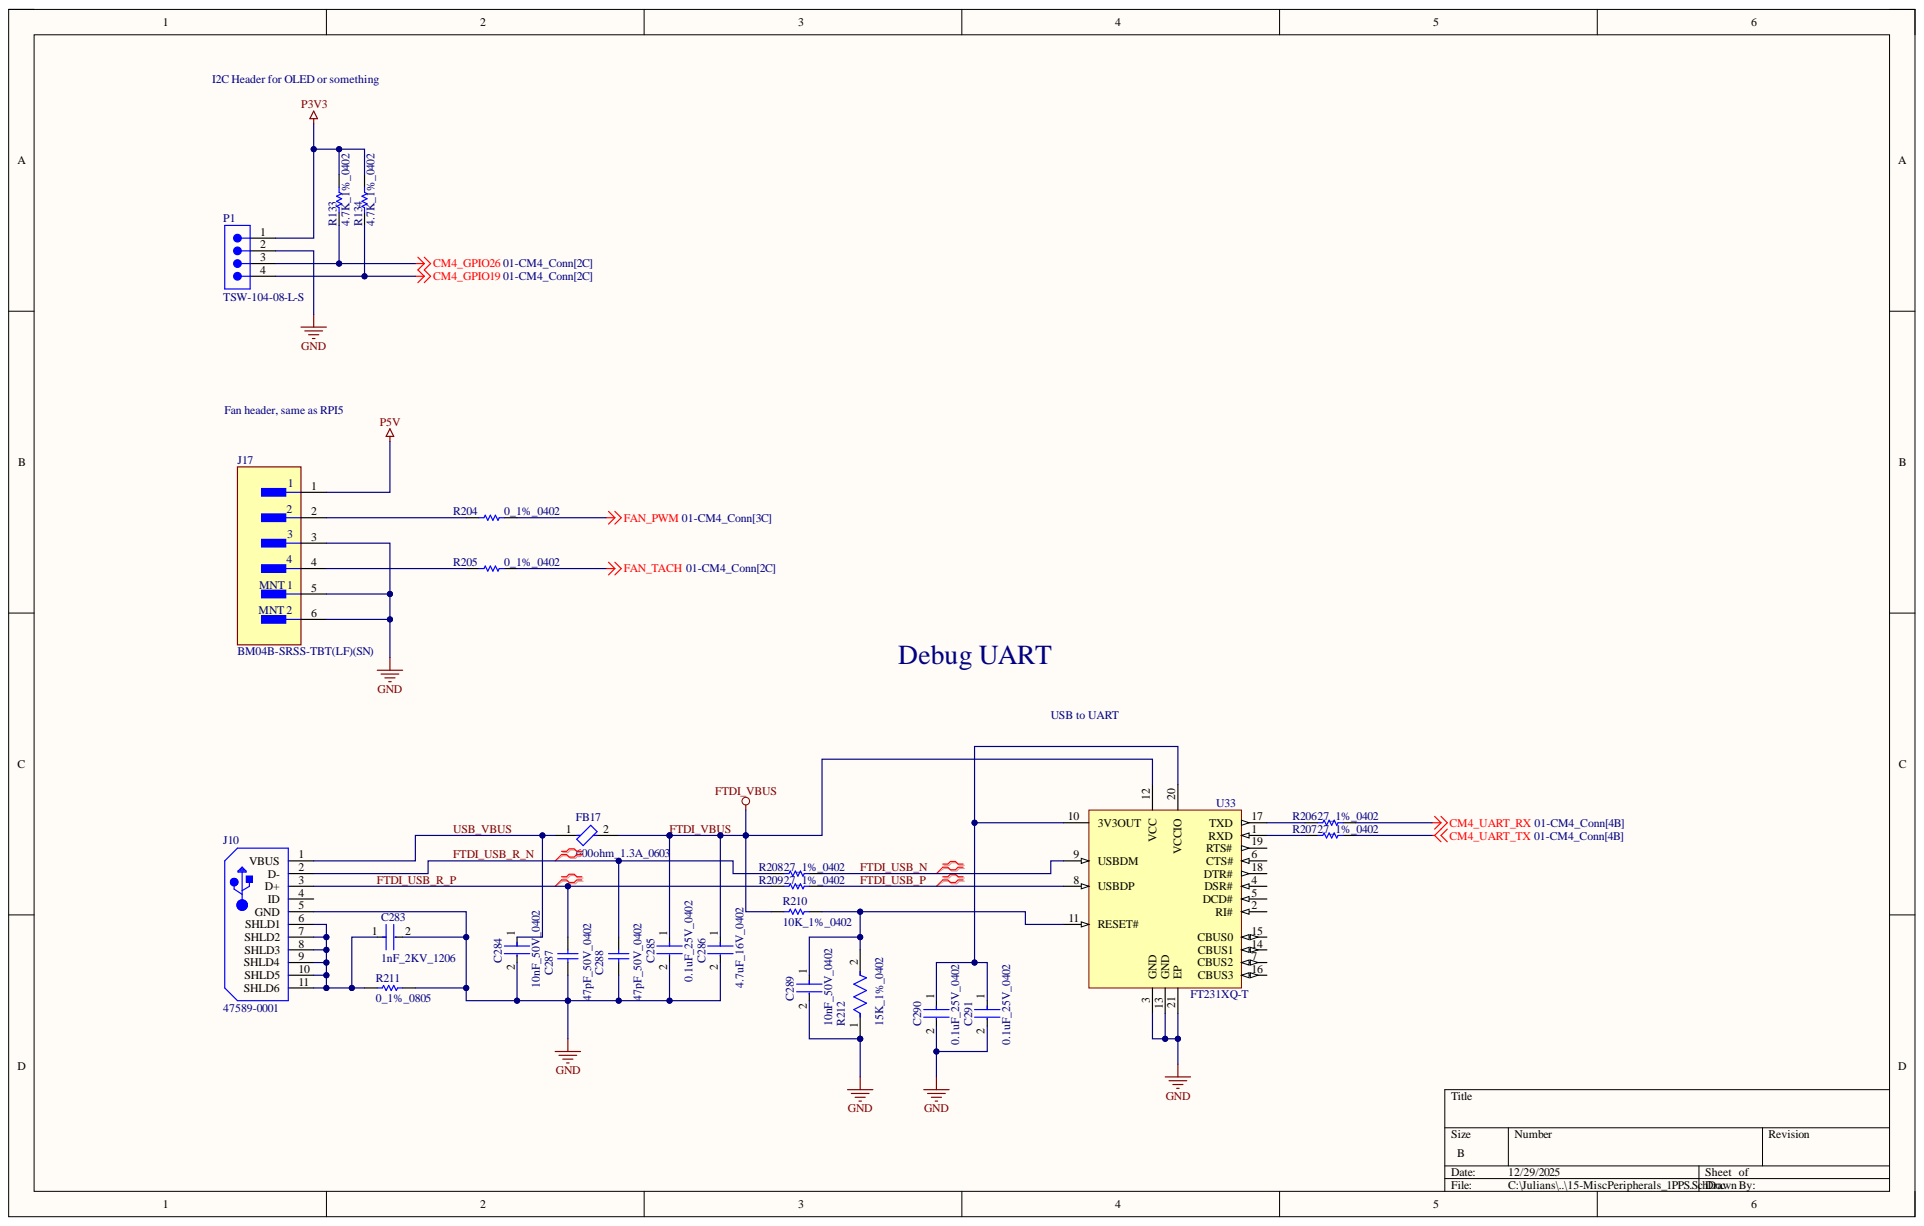
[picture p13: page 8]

I2C Header for OLED or something

Fan header, same as RPI5

BM04B-SRSS-TBT(LF)(SN)

Size B | Number | Revision

Date: 12/29/2025 | Sheet of
File: C:\Julians\..\15-MiscPeripherals_1PPS.SchDDroawc n By:

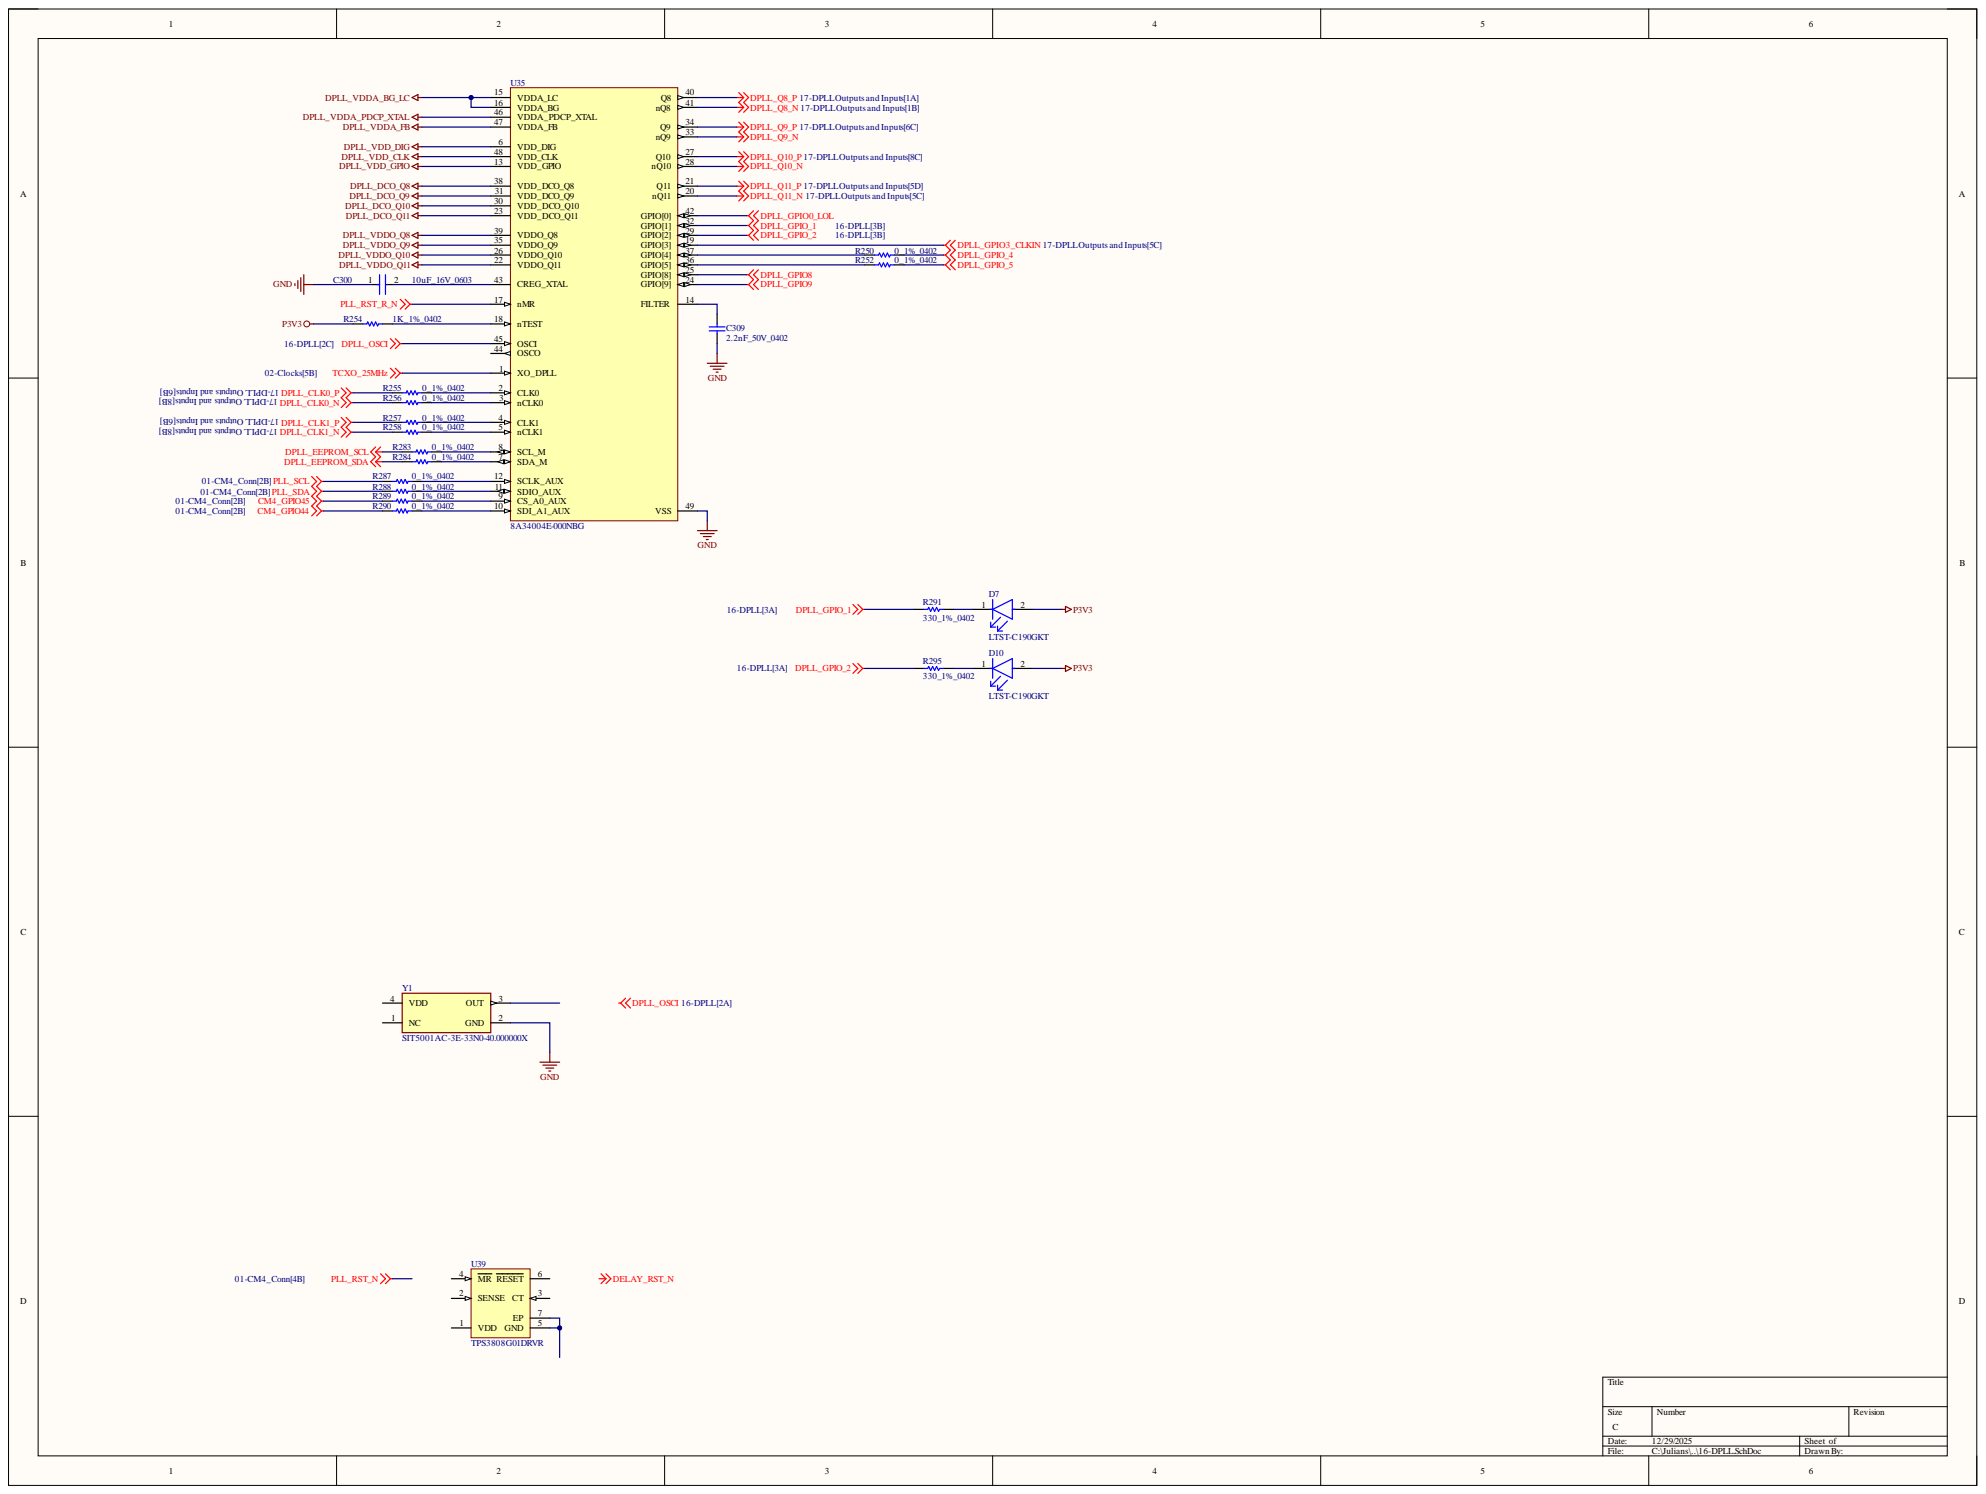
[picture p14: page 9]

DPLL_CLK0_P ] B6[st upnI dna st upt u OLLP D- 71
DPLL_CLK0_N ] B8[st upnI dna st upt u OLLP D- 71

DPLL_CLK1_P ] B6[st upnI dna st upt u OLLP D- 71
DPLL_CLK1_N ] B8[st upnI dna st upt u OLLP D- 71

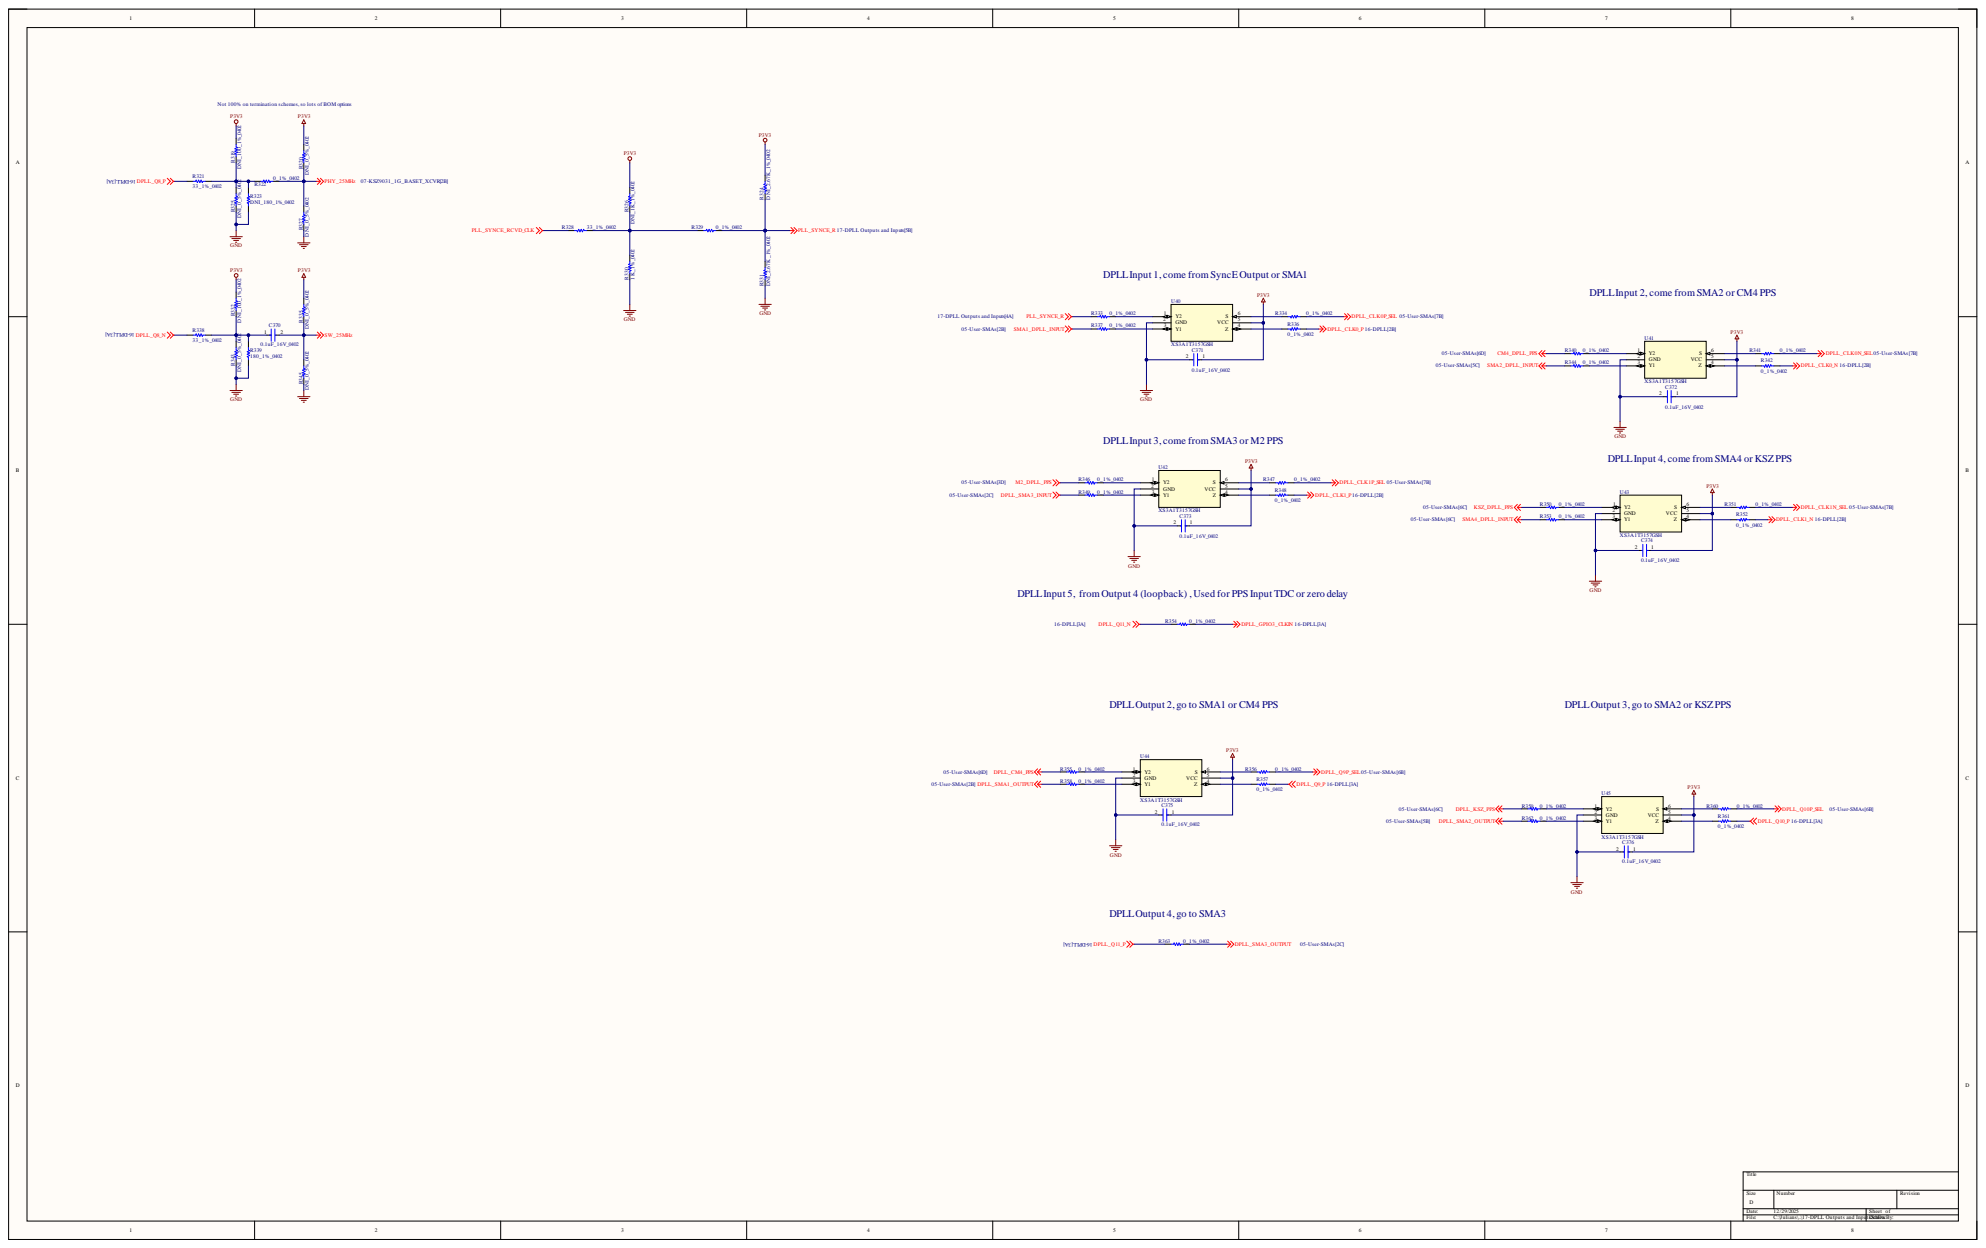
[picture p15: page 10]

Z | 4 | DPL L

Size DDat | N umb er | Rev i s ion

e: 1 2 / 2 9 /202 5 | Sheet o f
Fi l e: C: \J u l ian s \ . . \ 1 7-DPL L O u t p u t s an d In | p u t sD.SrawchDoncBy :

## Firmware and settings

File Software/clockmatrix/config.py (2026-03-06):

#!/usr/bin/env python3
import json
import argparse
from dataclasses import dataclass, asdict
from enum import Enum
from typing import List, Optional, Dict


# ---------- Enums ----------

class PtpRole(Enum):
    GM = "GM"
    CLIENT = "CLIENT"
    NONE = "NONE"


class TimeFreqRole(Enum):
    TIME_ONLY = "TIME_ONLY"
    FREQ_ONLY = "FREQ_ONLY"
    TIME_AND_FREQ = "TIME_AND_FREQ"
    NONE = "NONE"


class SmaDirection(Enum):
    INPUT = "INPUT"
    OUTPUT = "OUTPUT"
    UNUSED = "UNUSED"


# ---------- Dataclasses for config ----------

@dataclass
class GpsConfig:
    present: bool
    role: Optional[str] = None        # TimeFreqRole value or None if ignored
    priority: Optional[int] = None    # 1 = highest (applied to whichever domain(s) it affects)


@dataclass
class Cm4Config:
    used_as_source: bool
    role: Optional[str] = None        # usually TIME_ONLY or TIME_AND_FREQ
    priority: Optional[int] = None    # when used as source


@dataclass
class SyncEConfig:
    used_as_source: bool
    priority: Optional[int] = None    # FREQ_ONLY source
    recover_port: Optional[int] = None    # FREQ_ONLY source


@dataclass
class SmaConfig:
    name: str                         # "SMA1".."SMA4"
    direction: str                    # SmaDirection value
    role: Optional[str] = None        # TimeFreqRole (if INPUT)
    priority: Optional[int] = None    # priority (if INPUT)
    frequency_hz: Optional[int] = None  # desired output frequency (if OUTPUT), also used for input


@dataclass
class NetworkConfig:
    mode: str = "DHCP"                # "DHCP" or "STATIC"
    ip_address: Optional[str] = None
    cidr: Optional[int] = None
    gateway: Optional[str] = None
    dns: Optional[str] = None


@dataclass
class PtpConfig:
    transport: str = "UNICAST"        # "UNICAST" or "MULTICAST"
    master_ip: Optional[str] = None   # Only for CLIENT + UNICAST
    time_traceable: bool = True       # GM: advertise timeTraceable flag


@dataclass
class TimingConfig:
    ptp_role: str                     # PtpRole value
    gps: GpsConfig
    cm4: Cm4Config
    synce: SyncEConfig
    smas: List[SmaConfig]
    network: NetworkConfig = None      # eth0 network config (optional, defaults to DHCP)
    ptp: PtpConfig = None              # PTP transport config (optional, defaults to UNICAST)


# ---------- Helper: serialize / deserialize ----------

def config_to_json_dict(cfg: TimingConfig) -> dict:
    d = {
        "ptp_role": cfg.ptp_role,
        "gps": asdict(cfg.gps),
        "cm4": asdict(cfg.cm4),
        "synce": asdict(cfg.synce),
        "smas": [asdict(s) for s in cfg.smas],
    }
    if cfg.network is not None:
        d["network"] = asdict(cfg.network)
    if cfg.ptp is not None:
        d["ptp"] = asdict(cfg.ptp)
    return d


def config_from_json_dict(data: dict) -> TimingConfig:
    gps = GpsConfig(**data["gps"])
    cm4 = Cm4Config(**data["cm4"])
    synce = SyncEConfig(**data["synce"])
    smas = [SmaConfig(**s) for s in data["smas"]]
    # Backward compat: older JSON files may not have 'network' or 'ptp'
    network = NetworkConfig(**data["network"]) if "network" in data else NetworkConfig()
    ptp = PtpConfig(**data["ptp"]) if "ptp" in data else PtpConfig()
    return TimingConfig(
        ptp_role=data["ptp_role"],
        gps=gps,
        cm4=cm4,
        synce=synce,
        smas=smas,
        network=network,
        ptp=ptp,
    )


def save_config(path: str, cfg: TimingConfig) -> None:
    with open(path, "w") as f:
        json.dump(config_to_json_dict(cfg), f, indent=2)
    print(f"\nConfig written to {path}")


def load_config(path: str) -> TimingConfig:
    with open(path, "r") as f:
        data = json.load(f)
    return config_from_json_dict(data)


# ---------- Internal representation of an input source ----------

@dataclass
class InputSource:
    name: str            # "GPS", "CM4", "SYNC_E", "SMA1"..
    role: TimeFreqRole
    priority: int        # lower = higher priority


# ---------- Derivation + validation logic ----------

@dataclass
class DerivedPlan:
    """
    V6 DPLL Channel Architecture:
      - Channel 5: FREQUENCY DPLL - locks to SyncE or frequency inputs (FREQ_ONLY sources)
                   Also handles TIME_AND_FREQ sources (combined time+freq reference)
      - Channel 6: TIME/1PPS DPLL - locks to 1PPS sources (TIME_ONLY)
                   Combo bus slave of Channel 5 for frequency tracking
      - Channel 2: Not used in the V6 timing path (legacy, not configured by this tool)

    Q9 (on Ch5) drives SMA3 at fixed 10MHz.
    Q11 (on Ch6) drives CM4 1PPS (GM mode) or SMA1 (CLIENT mode).
    """
    channel5_inputs: List[InputSource]     # frequency DPLL (Ch5) - SyncE, FREQ_ONLY, or TIME_AND_FREQ
    channel6_inputs: List[InputSource]     # time/1PPS DPLL (Ch6) - TIME_ONLY, combo bus slave of Ch5
    warnings: List[str]
    errors: List[str]


def derive_plan(cfg: TimingConfig) -> DerivedPlan:
    """
    Derives the V6 DPLL Input Plan.

    V6 Architecture:
      - Channel 5 (Frequency): Locks ONLY to dedicated frequency sources.
          * FREQ_ONLY (e.g. SyncE, SMA with 10MHz)
          * If no FREQ_ONLY sources exist, Ch5 gets frequency via Combo Bus from Ch6.
      - Channel 6 (Time): Locks to any source providing 1PPS/Time.
          * TIME_AND_FREQ (e.g. GPS) - provides BOTH time and frequency to Ch6
          * TIME_ONLY (e.g. SMA with 1PPS)
      - Combo Bus direction is determined by apply_timing.py based on which channel
        has direct inputs.

    Logic:
      1. channel5_inputs = FREQ_ONLY only
      2. channel6_inputs = TIME_AND_FREQ + TIME_ONLY
      3. Sort both lists by priority (0=highest).
    """

    warnings: List[str] = []
    errors: List[str] = []

    ptp_role = PtpRole(cfg.ptp_role)

    # Build a flat list of InputSource from GPS, CM4, SyncE, and SMA inputs
    inputs: List[InputSource] = []

    # GPS
    if cfg.gps.present:
        # Default GPS priority=1 if not set
        prio = cfg.gps.priority if cfg.gps.priority is not None else 1
        role_enum = TimeFreqRole(cfg.gps.role)
        # Check explicit valid values
        if role_enum == TimeFreqRole.NONE:
            pass  # GPS present but role=NONE -> ignore
        else:
            inputs.append(InputSource(name="GPS", role=role_enum, priority=prio))

    # CM4
    if cfg.cm4.used_as_source:
        prio = cfg.cm4.priority if cfg.cm4.priority is not None else 2
        role_enum = TimeFreqRole(cfg.cm4.role)
        if role_enum != TimeFreqRole.NONE:
            inputs.append(InputSource(name="CM4", role=role_enum, priority=prio))

    # SyncE (Freq only)
    if cfg.synce.used_as_source:
        prio = cfg.synce.priority if cfg.synce.priority is not None else 3
        inputs.append(InputSource(name="SYNC_E", role=TimeFreqRole.FREQ_ONLY, priority=prio))

    # SMA Inputs
    for sma in cfg.smas:
        if sma.direction == SmaDirection.INPUT.value:
            # Must have priority
            if sma.priority is None:
                warnings.append(f"{sma.name} is INPUT but priority is not set. Ignoring.")
                continue
            
            # Must have role
            if sma.role is None:
                warnings.append(f"{sma.name} is INPUT but role is not set. Ignoring.")
                continue

            r = TimeFreqRole(sma.role)
            inputs.append(InputSource(name=sma.name, role=r, priority=sma.priority))


    # Setup source categories
    time_freq_sources = [s for s in inputs if s.role == TimeFreqRole.TIME_AND_FREQ]
    freq_only_sources = [s for s in inputs if s.role == TimeFreqRole.FREQ_ONLY]
    time_only_sources = [s for s in inputs if s.role == TimeFreqRole.TIME_ONLY]

    # V6 Logic: Populating Channel 5 (Freq) and Channel 6 (Time)
    channel5_inputs: List[InputSource] = []
    channel6_inputs: List[InputSource] = []

    # Channel 5 takes ONLY dedicated frequency sources (FREQ_ONLY)
    # TIME_AND_FREQ sources (like GPS) go to Channel 6 only;
    # Channel 5 gets frequency from Channel 6 via Combo Bus in that case.
    channel5_inputs.extend(freq_only_sources)
    channel5_inputs.sort(key=lambda s: s.priority)

    # Channel 6 takes anything with Time
    channel6_inputs.extend(time_freq_sources)
    channel6_inputs.extend(time_only_sources)
    channel6_inputs.sort(key=lambda s: s.priority)

    # Sanity checks
    
    # a) GM must have at least one time source (Ch6)
    if ptp_role == PtpRole.GM and not channel6_inputs:
        errors.append(
            "CM4 is configured as PTP GM, but there are no TIME or TIME_AND_FREQ sources "
            "for Channel 6 (Time/1PPS)."
        )

    # b) If we have Time sources but no Frequency sources, Ch5 is empty.
    #    This is OK - Ch5 will get frequency via Combo Bus from Ch6.
    if channel6_inputs and not channel5_inputs:
        warnings.append(
            "Channel 5 (Freq) has no direct inputs. It will get frequency "
            "via Combo Bus from Channel 6 (Time)."
        )

    # c) Check duplicate priorities per lists
    def find_duplicate_priorities(sources: List[InputSource], label: str):
        seen: Dict[int, List[str]] = {}
        for s in sources:
            seen.setdefault(s.priority, []).append(s.name)
        for prio, names in seen.items():
            if len(names) > 1:
                warnings.append(
                    f"{label}: multiple sources share priority {prio}: {', '.join(names)}."
                )

    find_duplicate_priorities(channel5_inputs, "Channel 5 (Freq) inputs")
    find_duplicate_priorities(channel6_inputs, "Channel 6 (Time) inputs")

    # d) SMA consistency checks + special SMA1 rules
    for sma in cfg.smas:
        if sma.direction == SmaDirection.OUTPUT.value:
            # SMA1 special: shares path with CM4 PPS, only 1PPS, and not allowed when GM
            if sma.name == "SMA1":
                if ptp_role == PtpRole.GM:
                    errors.append(
                        "SMA1 is configured as OUTPUT, but CM4 is PTP GM. "
                        "The SMA1 output shares the CM4 1PPS path, so SMA1 "
                        "cannot be used as an output in GM mode."
                    )
                if sma.frequency_hz not in (None, 1):
                    warnings.append(
                        "SMA1 is OUTPUT and frequency_hz is not 1; "
                        "hardware only supports 1PPS on SMA1. Treating SMA1 as 1PPS."
                    )
            else:
                # V6: SMA3 is on Q9/Ch5 (Frequency only)
                if sma.name == "SMA3":
                    # Warn if user tries to set 1PPS, as it won't be phase-aligned
                    if sma.frequency_hz == 1:
                        warnings.append(
                            "SMA3 is driven by Channel 5 (Freq DPLL) and cannot provide "
                            "phase-aligned 1PPS. Use SMA1 for phase-aligned 1PPS."
                        )
                    # We no longer force 10MHz, so we don't warn about "ignored" config.
                    # But we can warn that it is integer-divided from DCO.
                    pass

                elif sma.frequency_hz is None:
                    warnings.append(
                        f"{sma.name}: OUTPUT selected but frequency_hz is not set."
                    )

            if sma.role is not None or sma.priority is not None:
                warnings.append(
                    f"{sma.name}: OUTPUT selected, but input role/priority are set. "
                    "They will be ignored."
                )

    return DerivedPlan(
        channel5_inputs=channel5_inputs,
        channel6_inputs=channel6_inputs,
        warnings=warnings,
        errors=errors,
    )


# ---------- SMA Mapping Helpers ----------

def hw_to_user_sma(hw_name: str) -> str:
    """
    Maps Hardware SMA name (Schematic/Front-Panel) to User SMA name (Rear-Panel).
    Mapping (V6):
      HW SMA1 <-> User SMA4
      HW SMA2 <-> User SMA3
      HW SMA3 <-> User SMA2
      HW SMA4 <-> User SMA1
    
    Formula: User# = 5 - HW#
    """
    try:
        hw_num = int(hw_name.replace("SMA", ""))
        user_num = 5 - hw_num
        return f"SMA{user_num}"
    except ValueError:
        return hw_name

def user_to_hw_sma(user_name: str) -> str:
    """
    Maps User SMA name (Rear-Panel) to Hardware SMA name.
    """
    try:
        user_num = int(user_name.replace("SMA", ""))
        hw_num = 5 - user_num
        return f"SMA{hw_num}"
    except ValueError:
        return user_name


def validate_config(cfg: TimingConfig) -> DerivedPlan:
    plan = derive_plan(cfg)
    ptp_role = PtpRole(cfg.ptp_role)

    # Track whether the user configured any FREQ_ONLY sources in the *config*
    configured_freq_only = []

    if cfg.synce.used_as_source:
        configured_freq_only.append("SYNC_E")

    for sma in cfg.smas:
        if sma.direction == SmaDirection.INPUT.value and sma.role == TimeFreqRole.FREQ_ONLY.value:
            configured_freq_only.append(sma.name)

    print("=== Derived 8A34004 DPLL Plan (V6 Architecture) ===")
    print(f"PTP role: {cfg.ptp_role}")

    # ---- SyncE summary ----
    if cfg.synce.used_as_source:
        synce_prio = cfg.synce.priority if cfg.synce.priority is not None else "unset"

        # recover_port is new; allow older configs that don't have it yet.
        synce_port = getattr(cfg.synce, "recover_port", None)
        if synce_port is None:
            print(f"SyncE: enabled (front-panel recover_port=UNSET, priority={synce_prio})")
        else:
            print(f"SyncE: enabled (front-panel recover_port={synce_port}, priority={synce_prio})")
    else:
        print("SyncE: disabled")

    # ---- High-level mode note ----
    print("\nDPLL mode summary:")
    print("  Channel 5 (Frequency DPLL): Locks to FREQ_ONLY sources (SyncE, 10MHz).")
    print("  Channel 6 (Time/1PPS DPLL): Locks to TIME_AND_FREQ and TIME_ONLY sources.")
    if plan.channel5_inputs:
        print("  Combo Bus: Channel 6 slaves to Channel 5 (Freq Master).")
    elif plan.channel6_inputs:
        print("  Combo Bus: Channel 5 slaves to Channel 6 (Time Master, no direct freq source).")
    else:
        print("  Combo Bus: disabled (no sources).")

    # ---- Channel 5 list ----
    print("\nChannel 5 (Frequency) input priority list:")
    if plan.channel5_inputs:
        for s in plan.channel5_inputs:
            uname = s.name
            if s.name.startswith("SMA"):
                uname = f"{s.name} (User {hw_to_user_sma(s.name)})"
            print(f"  priority {s.priority}: {uname} ({s.role.value})")
    else:
        print("  (no frequency sources configured)")

    # ---- Channel 6 list ----
    print("\nChannel 6 (Time/1PPS) input priority list:")
    if plan.channel6_inputs:
        for s in plan.channel6_inputs:
            uname = s.name
            if s.name.startswith("SMA"):
                uname = f"{s.name} (User {hw_to_user_sma(s.name)})"
            print(f"  priority {s.priority}: {uname} ({s.role.value})")
    else:
        print("  (no time sources configured)")

    # ---- SMA summary (existing behavior) ----
    print("\nSMA configuration (showing Hardware Names [User Rear Panel Names]):")
    # Sort for display by User Number (Rear 1..4) implies HW 4..1
    # Let's just iterate the config list order, but adding User mappings
    
    # Actually, let's sort by User Name for approachability
    sorted_smas = sorted(cfg.smas, key=lambda s: hw_to_user_sma(s.name))
    
    for sma in sorted_smas:
        user_name = hw_to_user_sma(sma.name)
        label = f"{sma.name} [{user_name}]"
        
        if sma.direction == SmaDirection.INPUT.value:
            print(f"  {label}: INPUT, role={sma.role}, priority={sma.priority}, frequency={sma.frequency_hz}")
        elif sma.direction == SmaDirection.OUTPUT.value:
            if sma.name == "SMA1":
                if ptp_role == PtpRole.GM:
                    print(f"  {label}: OUTPUT, 1PPS (GM mode: Q11 forced to 1PPS for CM4)")
                else:
                    print(f"  {label}: OUTPUT, frequency={sma.frequency_hz} Hz (via Q11/Ch6, phase-aligned)")
            elif sma.name == "SMA2":
                print(f"  {label}: OUTPUT, frequency={sma.frequency_hz} Hz (via Q10)")
            elif sma.name == "SMA3":
                freq = sma.frequency_hz if sma.frequency_hz is not None else 10_000_000
                DCO_HZ = 500_000_000
                divider = round(DCO_HZ / freq)
                if divider < 1: divider = 1
                actual_hz = DCO_HZ / divider
                error_ppm = ((actual_hz - freq) / freq) * 1e6 if freq > 0 else 0
                if abs(error_ppm) > 0.001:
                    print(f"  {label}: OUTPUT, frequency={freq} Hz (via Q9/Ch5, output divider={divider}, actual={actual_hz:.3f} Hz, error={error_ppm:+.3f} ppm)")
                else:
                    print(f"  {label}: OUTPUT, frequency={freq} Hz (via Q9/Ch5, output divider={divider})")
            else:
                print(f"  {label}: OUTPUT, frequency={sma.frequency_hz} Hz")
        else:
            print(f"  {label}: UNUSED")

    if plan.warnings:
        print("\nWarnings:")
        for w in plan.warnings:
            print(f"  - {w}")

    if plan.errors:
        print("\nErrors:")
        for e in plan.errors:
            print(f"  - {e}")
    else:
        print("\nConfig is valid (no errors).")

    return plan


# ---------- Interactive wizard ----------
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

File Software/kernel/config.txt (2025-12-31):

# For more options and information see
# http://rptl.io/configtxt
# Some settings may impact device functionality. See link above for details

# Uncomment some or all of these to enable the optional hardware interfaces
#dtparam=i2c_arm=on
#dtparam=i2s=on
dtparam=spi=on

# Enable audio (loads snd_bcm2835)
dtparam=audio=on

# Additional overlays and parameters are documented
# /boot/firmware/overlays/README

# Automatically load overlays for detected cameras
camera_auto_detect=1

# Automatically load overlays for detected DSI displays
display_auto_detect=1

# Automatically load initramfs files, if found
auto_initramfs=1

# Enable DRM VC4 V3D driver
dtoverlay=vc4-kms-v3d
max_framebuffers=2

# Don't have the firmware create an initial video= setting in cmdline.txt.
# Use the kernel's default instead.
disable_fw_kms_setup=1

# Run in 64-bit mode
arm_64bit=1

# Disable compensation for displays with overscan
disable_overscan=1

# Run as fast as firmware / board allows
arm_boost=1

[cm4]
# Enable host mode on the 2711 built-in XHCI USB controller.
# This line should be removed if the legacy DWC2 controller is required
# (e.g. for USB device mode) or if USB support is not required.
otg_mode=1

[cm5]
dtoverlay=dwc2,dr_mode=host

[all]
enable_uart=1
uart_2ndstage=1
dtoverlay=disable-bt
dtoverlay=switchberrytc
#dtoverlay=ksz9567
dtoverlay=spi0-1cs
dtoverlay=uart5,txd5_pin=12,rxd5_pin=13
dtoverlay=pcie-32bit-dma
dtparam=i2c_vc=off

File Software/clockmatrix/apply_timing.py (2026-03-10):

#!/usr/bin/env python3
import argparse
import subprocess
import math
from typing import Dict, Tuple

# Import your existing config logic
# Make sure config.py (the wizard/validate script) is in the same directory or PYTHONPATH.
from config import TimingConfig, load_config, derive_plan, PtpRole, TimeFreqRole

# ---------- Constants ----------
DCO_FREQ_HZ = 500_000_000  # 500 MHz nominal DCO frequency (default for 8A3400x)


# ---------- Utility for running shell commands ----------

def run(cmd, dry_run: bool = False):
    print("RUN:", " ".join(cmd))
    if not dry_run:
        subprocess.run(cmd, check=True)


# Helper: User (Rear) vs HW (Front) mapping for logging
def get_user_sma_name(hw_name: str) -> str:
    # HW SMA1 <-> User SMA4
    # HW SMA2 <-> User SMA3
    # HW SMA3 <-> User SMA2
    # HW SMA4 <-> User SMA1
    if hw_name == "SMA1": return "User SMA4"
    if hw_name == "SMA2": return "User SMA3"
    if hw_name == "SMA3": return "User SMA2"
    if hw_name == "SMA4": return "User SMA1"
    return hw_name



# ---------- Mapping: logical source name -> DPLL input index ----------


# ---------- Logical DPLL input index (1..4) -> physical index mapping ----------

def logical_to_physical_input_idx(logical_idx: int) -> int:
    """
    Map logical DPLL input indices (1..4) to physical DPLL input indices, as used
    by dplltool now.

      Logical 1 -> Physical 0
      Logical 2 -> Physical 8 (N of 0)
      Logical 3 -> Physical 1
      Logical 4 -> Physical 9 (N of 1)
    """
    mapping = {
        1: 0,
        2: 8,
        3: 1,
        4: 9,
    }
    try:
        return mapping[logical_idx]
    except KeyError:
        raise ValueError(f"Invalid logical DPLL input index {logical_idx}, "
                         f"expected 1..4")


def map_source_to_input_idx(source_name: str) -> int:
    """
    Map high-level source name from config/plan to a physical DPLL input index.

    Based on your board wiring:
      - DPLL Input 1 -> SyncE OR SMA1 input path
      - DPLL Input 2 -> SMA2 input path OR CM4 1PPS
      - DPLL Input 3 -> SMA3 input path OR GPS PPS path
      - DPLL Input 4 -> SMA4 (no mux)
    """
    if source_name == "GPS":
        return 3
    if source_name == "SYNC_E":
        return 1
    if source_name == "CM4":
        return 2
    if source_name == "SMA1":
        return 1
    if source_name == "SMA2":
        return 2
    if source_name == "SMA3":
        return 3
    if source_name == "SMA4":
        return 4

    raise ValueError(f"Unknown source name '{source_name}' in plan → input mapping.")


# ---------- Infer nominal input frequency for each source ----------

def nominal_input_freq_hz(source_name: str, role: TimeFreqRole) -> int:
    """
    Guess the nominal input frequency for the DPLL per source type.
    Adjust these numbers to match your actual design:

      - TIME_ONLY/TIME_AND_FREQ 1PPS sources → 1 Hz
      - FREQ_ONLY SMA inputs     → 10 MHz (assumed)
      - SyncE                    → 25 MHz (assumed)

    You can tweak these constants or even move them into the JSON later if needed.
    """
    if role in (TimeFreqRole.TIME_ONLY, TimeFreqRole.TIME_AND_FREQ):
        # 1PPS default
        return 1

    # FREQ_ONLY cases:
    if source_name == "SYNC_E":
        return 25_000_000  # adjust as appropriate for your switch
    if source_name.startswith("SMA"):
        return 10_000_000   # assumed external 10 MHz
    # Fallback
    return 10_000_000


# ---------- Configure board multiplexers via gpioset ----------
def configure_muxes(cfg: TimingConfig, dry_run: bool = False):
    """
    Configure all board-level multiplexers via gpioset based on the chosen config.

    Multiplexer layers (board-level, not inside the DPLL):

    1. SMA-side muxes:
        SMA1 -> GPS 1PPS direct OR to DPLL IN1 OR from DPLL Q11 (Ch6 1PPS)
        SMA2 -> CM4 1PPS direct OR to DPLL IN2 OR from DPLL OUT3
        SMA3 -> to DPLL IN3 OR from DPLL Q9 (Ch5 frequency-only)
        SMA4 -> fixed to DPLL IN4 (no mux)

    2. DPLL-input-side muxes:
        DPLL IN1 -> SyncE OR SMA1 path
        DPLL IN2 -> SMA2 path OR CM4 1PPS connection
        DPLL IN3 -> SMA3 path OR GPS 1PPS path
        DPLL IN4 -> SMA4 path (fixed)

    3. 1PPS destination (Q11, Channel 6):
        DPLL Q11 -> SMA1 path OR CM4 PPS

    4. Frequency output (Q9, Channel 5):
        DPLL Q9 -> SMA3 (frequency-only, phase-locked to SyncE)

    NOTE: V6 board change - Q9 and Q11 swapped:
      - Q9 (Ch5): now drives SMA3 for frequency output (SyncE aligned)
      - Q11 (Ch6): now drives CM4 1PPS / SMA1 for phase output
      This separates SyncE frequency from 1PPS phase alignment,
      allowing large phase jumps on Ch6 without disturbing SyncE 25MHz.

    This function decides all of that based on:
      - cfg.ptp_role (GM / CLIENT / NONE)
      - cfg.gps
      - cfg.cm4
      - cfg.synce
      - cfg.smas[*].direction / role

    NOTE:
      - GPIO numbers used here (chip, line) match your snippet for the SMA and CM4 muxes.
      - DPLL input mux GPIOs are placeholders: replace DPLL_INx_SEL_* with real lines.
    """

    ptp_role = PtpRole(cfg.ptp_role)

    # ----------------------------------------------------------------------
    # 1. CM4 <-> DPLL OUT2 / IN2 mux (your 10,11,14,16 gpios)
    # ----------------------------------------------------------------------
    sma1_cfg = next(s for s in cfg.smas if s.name == "SMA1")

    if ptp_role == PtpRole.GM:
        # CM4 is GM: DPLL Q11 (Ch6 1PPS) should go TO CM4 1PPS input.
        # CM4 multiplexer, output 1, CM4_MUX_SEL[1:0] = 2'b00
        print("CM4 is PTP GM: route DPLL Q11 (Ch6 1PPS) -> CM4 1PPS input")
        run(["gpioset", "-t", "0", "-c", "gpiochip2", "10=0", "11=0"], dry_run=dry_run)
        # V6: Enable DPLL Q11 (Ch6 1PPS) to go to CM4 (was Q9 in V5)
        # Q11 is now the 1PPS output, Q9 is frequency-only for SMA3
        print("Setup DPLL Q11 (Ch6 1pps) to go to CM4")
        run(["gpioset", "-t", "0", "-c", "gpiochip2", "16=1"], dry_run=dry_run)
        # enable CLK0N to come from SMA2
        print(f"Setup CLK0N to potentially come from SMA2")
        run(["gpioset", "-t", "0", "-c", "gpiochip2", "14=0"], dry_run=dry_run)
    else:
        # CM4 is CLIENT or NONE: CM4 1PPS goes TO DPLL input 2.
        # CM4 multiplexer, output 2, CM4_MUX_SEL[1:0] = 2'b01
        print("CM4 is PTP CLIENT/NONE: route CM4 1PPS -> DPLL IN2")
        run(["gpioset", "-t", "0", "-c", "gpiochip2", "10=1", "11=0"], dry_run=dry_run)        
        # 14=1: enable CM4 PPS path towards DPLL IN2 (per your comment)
        print("Setup CLK0N to potentially come from CM4")
        run(["gpioset", "-t", "0", "-c", "gpiochip2", "14=1"], dry_run=dry_run)
        # V6: enable Q11 (Ch6 1PPS) to go to SMA1 otherwise (was Q9 in V5)
        print(f"Setup Q11 (Ch6 1PPS) to potentially go to SMA1 ({get_user_sma_name('SMA1')})")
        run(["gpioset", "-t", "0", "-c", "gpiochip2", "16=0"], dry_run=dry_run)
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

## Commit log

2025-12-30 Add enclosure STL files and instructions.
    [Switchberry_Case_v5_Bottom.stl, Switchberry_Case_v5_Top.stl]
2025-12-31 Switchberry Software
    [config.txt]
2025-12-31 Switchberry update
2026-01-05 Switchberry SW
2026-01-06 Local Linuxptp to fix cm4 ptp4l issue
    [CMLDS_client.cfg, CMLDS_server.cfg, E2E-TC.cfg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]
2026-01-07 ptp4l debug
    [CMLDS_client.cfg, CMLDS_server.cfg, E2E-TC.cfg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]
2026-01-07 Update case design files with new clock easter egg.
    [Switchberry_Case_v5_Bottom.stl, Switchberry_Case_v5_Top.stl]
2026-02-10 Switchberry V6 updating software
2026-02-11 Switchberry v6 software updates
2026-03-06 PTP traceable update
2026-03-06 ptp4l fix and chmod fix
    [generate_ptp_conf.py]
